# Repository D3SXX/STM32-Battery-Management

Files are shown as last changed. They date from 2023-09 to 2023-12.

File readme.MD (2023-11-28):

# STM32 BATTERY MANAGEMENT PROJECT (DEVELOPMENT BRANCH)

For project information use [docs/project-information.MD](/docs/project-information.MD)

# Project Directory Map

/docs ------ Different documentations.

/docs/KiCAD Files ------ KiCAD schematics, simulations and PCB layouts.

/examples ------ researching study projects about mux, adc using LL library.

/lib ------ Project libraries.

/src ----- main.c

/scrum_reports ------ self explaintory.

/iot-ticket ------ iot-ticket related project

/iot-ticket/iotticket ------ iot-ticket client library.

/iot-ticket/fucking_mockingdata.py ------ the python Modbus Master/Cient to IoT-Ticket client gateway application. Naming is "bit" controversial, but it is what it is.

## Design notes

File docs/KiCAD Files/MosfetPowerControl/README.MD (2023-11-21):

# Mosfet Power Control

## Mosfet Basics

### Types

The **metal-oxide-semiconductor field-effect transistor** ( **MOSFET** ,  **MOS-FET** , or  **MOS FET** ) is a type of [field-effect transistor](https://en.wikipedia.org/wiki/Field-effect_transistor "Field-effect transistor") (FET), is basically a digital switche controlled by it's gate. There are normally three terminals, Drain, Source and Gate. The gate controls the current flow through D-S or S-D. There are N-Channel mosfet, P-Channel mosfet. And there enhancement type and depletion type of each.
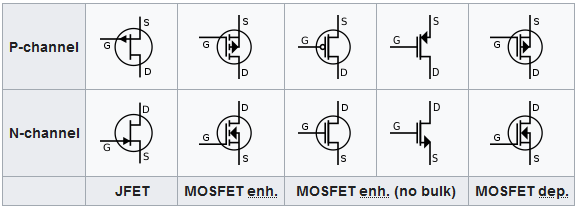
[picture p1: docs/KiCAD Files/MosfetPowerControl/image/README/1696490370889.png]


https://en.wikipedia.org/wiki/MOSFET

### Body diode

The existance of body diode in mosfet causing the current could flow to the forward direction of the body diode, even though the gate is off.

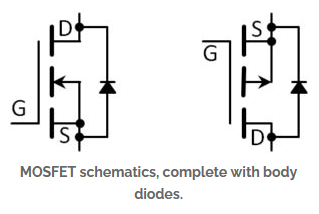
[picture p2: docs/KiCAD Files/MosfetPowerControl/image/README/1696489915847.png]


# FDS6890A

FDS6890A is Dual N-channel mosfets in SO-8 package. With following characteristics.
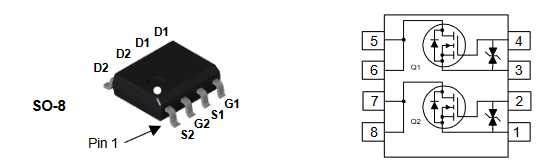
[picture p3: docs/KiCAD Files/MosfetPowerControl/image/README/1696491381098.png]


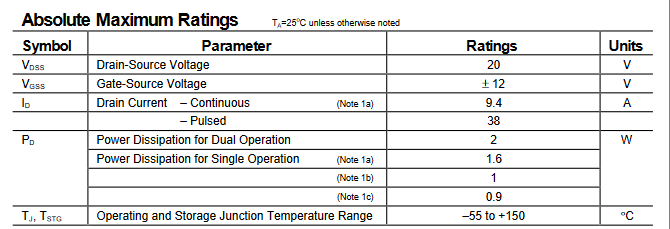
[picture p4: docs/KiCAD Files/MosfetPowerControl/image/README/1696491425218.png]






## Terminology

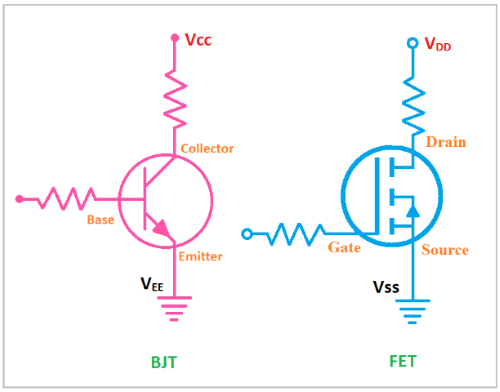
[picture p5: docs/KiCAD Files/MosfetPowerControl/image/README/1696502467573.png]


https://woopcb.com/blog/what-is-vcc-vss-vdd-vee-in-electronics

## N-Channel Mosfets in series

N-Channel Mosfets in series offer extra control of the current due to in body diode. And puting mosfet-series-array in parrallel allow the mosfets to handle more current. In theory I_total_max = I_mosfet_max * N

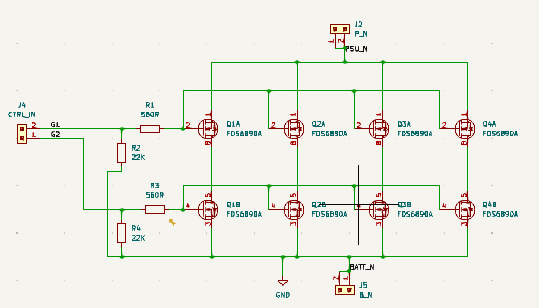
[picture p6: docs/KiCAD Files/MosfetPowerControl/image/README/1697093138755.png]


Be aware, the physical diodes D1 and D2 were added only for demostration of in body diode of the N-Channel mosfet. There's no actual physical dioded added to the circuit.

The current control follows the following truth table.

| Gate 0 | Gate 1 | Current Direction | Charing | Discharging |
| --- | --- | --- | --- | --- |
| 0 | 0 | None | NA | NA |
| 0 | 1 | Up to Bottom | OFF | ON |
| 1 | 0 | Bottom to Up | ON | OFF |
| 1 | 1 | Bidirectio | ON | ON |

https://www.powerelectronictips.com/remember-mosfet-body-diode-faq/

* Pull Down Resister: 22K
* IO current limit Resister: Ceil(3.3V / 25mA * 4) = 560R

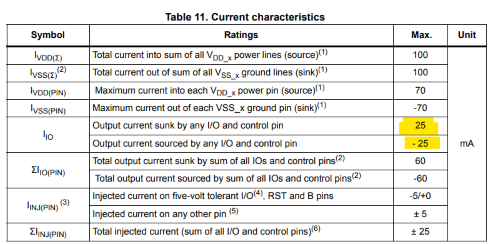
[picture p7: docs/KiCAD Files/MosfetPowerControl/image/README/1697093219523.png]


### PCB Circuit

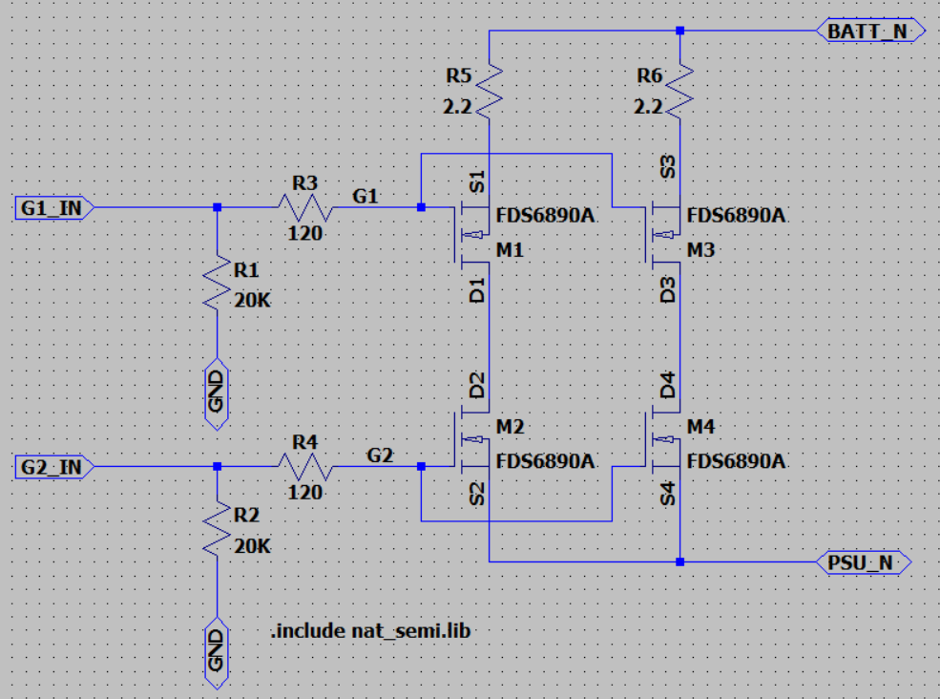
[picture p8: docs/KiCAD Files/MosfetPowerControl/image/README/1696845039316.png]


### Simulation

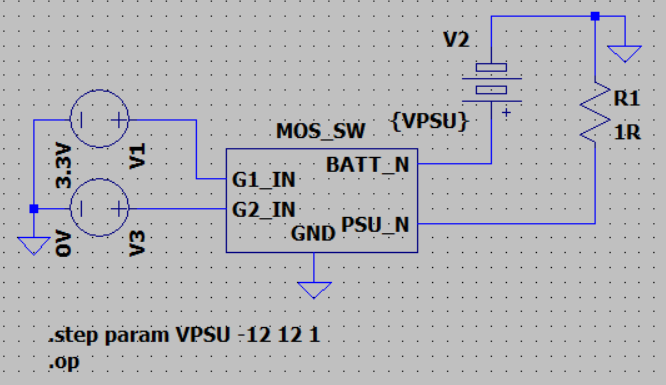
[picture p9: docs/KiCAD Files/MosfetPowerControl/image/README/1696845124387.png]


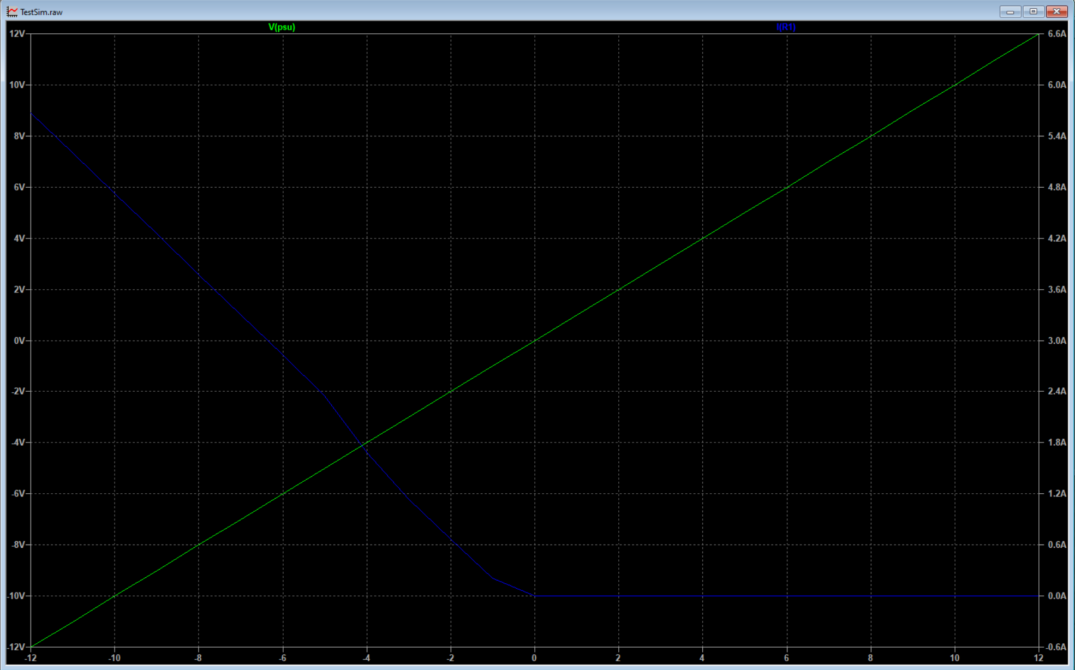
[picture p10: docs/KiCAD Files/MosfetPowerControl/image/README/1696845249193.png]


## Control Logic In Practice

The maximum On state drain-source current and Off state drain-source diode forward current are 9.4A and 1.3A respectively. Therefore, we couldn't simply just allow the charging and discharging to occure without extra control.

- Start condition (0, 0)
- Discharging not allowed, charging allowed. (0, 1)
- Now the charging current ramps up --> also turn on the discharging MOSFET, say 1A. (1, 1)
- Charging drops below 1A, disable discharging MOSFET again to make sure we don't get to discharging. (0, 1)

--> keep in mind that
battery can either be charging or discharging, so if there is enough
power on the input (say solar) to power the load and charge battery,
nothing will come from the battery. If the load is higher than what
solar can provide, part of the required power comes from the battery.

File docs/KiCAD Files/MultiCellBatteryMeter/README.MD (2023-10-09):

# Terminology

## Rail-To-Rail OPAMP

The power supply units of PCs and other devices incorporate multiple DC power supplies. A power supply line provided by a power supply unit is referred to as a power rail. The entire range from the maximum voltage of a power line (V ~CC~ ) to its minimum voltage (GND or minimum negative voltage, V ~EE~ ) is referred to as rail-to-rail.
"*Rail-to-rail* " is a marketing term used to describe an op amp whose dynamic range is able to reach the extremes of the supply voltage. This can refer to either the output or both the input and output.

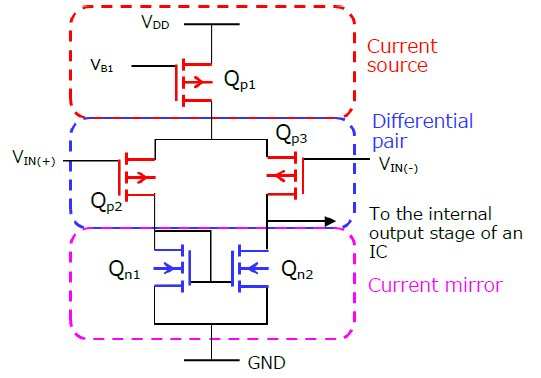
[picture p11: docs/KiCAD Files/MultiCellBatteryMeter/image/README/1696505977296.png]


https://toshiba.semicon-storage.com/ap-en/semiconductor/knowledge/faq/linear_opamp/what-does-rail-to-rail-mean.html

https://electronics.stackexchange.com/questions/224159/what-does-rail-to-rail-output-opamp-mean

## Electric Shunt

A **shunt** is a device that is designed to provide a low-resistance path for an electrical current in a circuit. There are many applications of an electric shunt, such as Defective device bypass, Photovoltaics, Lightning arrester and Current measuring.

### Current Measuring Shunt

Basically it is the technique to which uses a very small known resistor in series to the circuit to calculate the current by measuring the voltage difference between the resistor. There different positons such as High Side and Low Side. There can be circuit for Uni-direction current sensing and Bi-direction current sensing. In this project Bi-direction current sensing design was used, because of the current flow of the battery are bi-directional, charing and discharging.

https://www.analog.com/en/app-notes/an-105fa.html

In thie project, the shunt needs to detect bi-directional current. Therefore, the extra circuit is needed to convert voltage from range[-4V, +4-V] to range[0V, 3V].

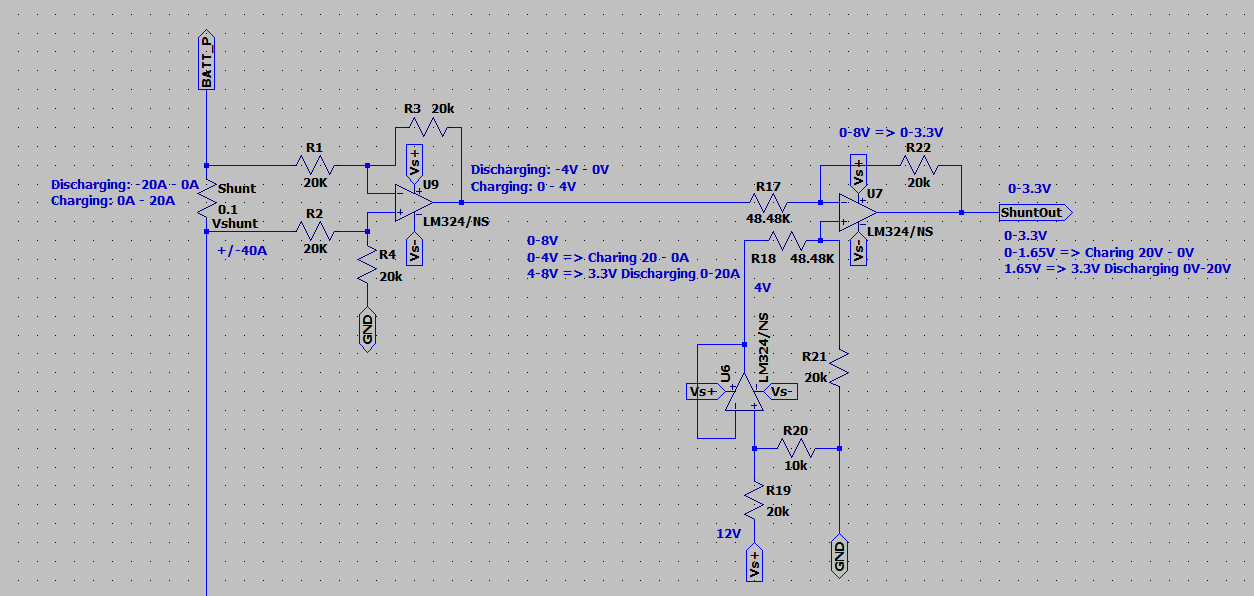
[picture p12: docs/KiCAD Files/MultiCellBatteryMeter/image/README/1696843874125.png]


### Differential Input Amplifier

As the name implies.

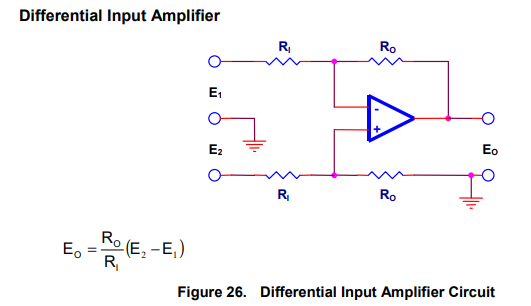
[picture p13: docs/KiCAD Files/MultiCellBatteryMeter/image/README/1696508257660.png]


Texas Instrument 00_opam_handbook.pdf P.24

## Multi Cell Battery Meter Circuit

In order to measure each cell's voltage accurately, Differential Input Amplifiers were used. And a 3-to-8 multiplexer was used to reduce the ADC I/O demands on Microcontroller. This design also left room for four extra battery cells. 

### Indivitual Voltage Meter Circuit

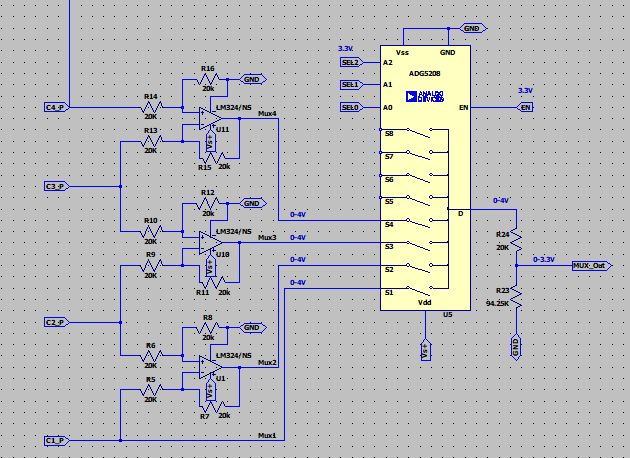
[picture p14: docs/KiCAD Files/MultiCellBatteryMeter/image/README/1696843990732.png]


### Simulation Circuit

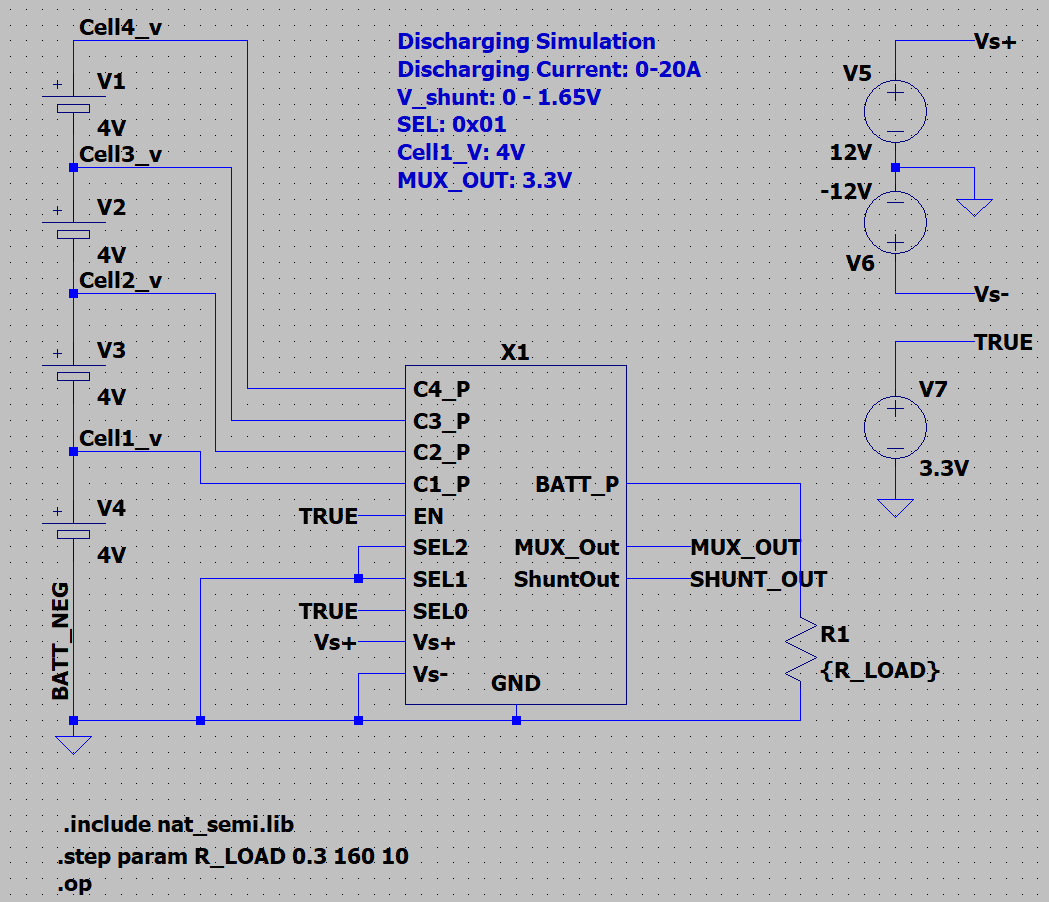
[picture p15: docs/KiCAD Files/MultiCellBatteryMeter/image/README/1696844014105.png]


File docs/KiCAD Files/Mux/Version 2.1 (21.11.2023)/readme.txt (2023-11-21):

Mux board version 2.1 by Vlad R.
Modified version of Mux board
Changes are -
Add physical labels to the outputs
Better copper pour

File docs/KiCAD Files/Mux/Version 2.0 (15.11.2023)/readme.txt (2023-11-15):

Mux board version 2.0 by Vlad R.
Modified version of Mux board
Changes are -
Names for pins and connections were taken straight from the datasheet for consistency
The Schematic was simplified by using more different output socket pins
Pcb was remade from scratch to reduce the number of jumpwires (now it is 0) and to make it more easier to set up.
Also pcb design now uses only 0.8mm traces

Changes from the already made PCB -
Name is now mirrored correctly

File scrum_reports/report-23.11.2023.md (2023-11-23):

# Report 23.11.2023

- Host - Vladislav

- Participants - Siyuan, Samuel, Sergiu

## Group Progress:

- ### Siyuan:
Added Pin Mappings and modbus function documentation (excel)

### Software Libraries
-	libadc
-	libmux
-	libbattery-manager

### Unit-Testings
#### Native Testing
-	test_adc
-	test_battery-manager
-	test_crc

### Hardware in Loop (embedded) Testing
-	test_adc
-	test_modbus
-	test_mosfet
-	test_mux

### PCB
-	soldered and tested mosfet control module

### Bugfixes
#### Bugs found during testing
-	adc
-	mux
-	modbus
-	battery-manager

- ### Samuel:
Made PCB for OP AMP circuit, tested the opAmp pcb, helped to make adc, helped with module control testing

- ### Sergiu: 
Light PCb design design, Made some PCBs, changed/fixed Unit tests

- ### Vladislav: 
Mux board, Unit tests

## Block:

- Siyuan: Where is the time?

- Samuel: Nothing to do

- Sergiu: A little bit of everything

- Vladislav: Not enough for everything

## TODO:

- Siyuan - FFinish the software, System Testing

- Samuel: Look at unit testing, System Testing

- Sergiu: Test some PCBs, System Testing

- Vladislav: Update code for mux testing, System Testing

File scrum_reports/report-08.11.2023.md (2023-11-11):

# Report 08.11.2023

- Host - Siyuan
- Participants - Vladislav, Samuel, Sergiu

## Group Progress:

- Siyuan: LM324 QUAD modelling in NGSpice,
MultiCellVoltMeter Schema simulation + PCB on kicad,
ShuntCurrentSensor Schema simulation + PCB on kicad,
Mux module         Schema simulation + PCB on kicad,
PlatformIO Unit Test setup for Native (test without the hardware)

- Samuel: Protyping the shunt current sensor on copperboard

- Vladislav: Sweden!!!

- Sergiu: Tried PCB design, Sweden

## Block:

- Siyuan: Where is the time?

- Samuel: Waiting for PCB design, waiting for Mosfet PCB arrive

- Vladislav: Learning new stuff

- Sergiu: Time management

## TODO:
- Siyuan - PCBs, embedded Testing,
Organize the project directory according to PlatformIO for easier Testing.

- Samuel: Make PCBs

- Vladislav: CI for github, help with making PCB

- Sergiu: Unit Test, soldering the PCB, joule Heating formula

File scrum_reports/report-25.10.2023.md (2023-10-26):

# Report 25.10.2023

- Host - Siyuan

- Participants - Samuel, Vladislav 

## Group progress:

- Samuel: Had own hobby studies on oscillators

- Vladislav: Vacation

- Siyuan: Researching ADC and designing the software architecture

## Block:

- Samuel: Nothing to do

- Vladislav: Nothing to do

- Siyuan: Limited time, STM32 is missing (And Found).

## TODO:

- Samuel: Will do the current sensing circuit and PCB

- Vladislav: LM35 Temperature

- Siyuan: Optimize, refactor and ADC code from Vlad.
Test the code.
Organize the Git repo.
Theory Support if needed.

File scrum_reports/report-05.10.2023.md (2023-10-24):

# Report 05.10.2023

- Host : Siyuan
- Participants: Samuel, Vladislav, Sergiu

## Group Progress:

- Siyuan: Modbus is ready, MOSFET control circuit , documentation for Mosfets
- Sergiu: Made ADC circuit circuit
- Sam: MOSFET circuit, electrical design of it, tested it using spice , breadboard
Vlad: ADC Measurements 

## TODO:
- Sam: Make a proper PCB
- Sergiu: Make a proper PCB, merge all branches 
- Siyuan: Logic, rtos

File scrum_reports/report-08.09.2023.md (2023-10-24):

# Report 08.09.2023 

- Host – Vladislav 

- Participants – Siyuan, Samuel, Sergiu 

## Github

- Is anyone experiencing any problems with github? 

- Everyone has access and can edit? 

### All - Good 

### Project 

- Everyone understands concept? 

- A quick run thru the project details so everyone understands 

- A quick description of the project will be published on GitHub with all the details 

### All - good 

## Embedded side

- What are we measuring? 

- How do we measure it? 

- What parts needed to be done 

- Software for project 

- CI/CD and unit testing (was only mentioned) 

### All – good, information can be found in docs/project-info.md 

## Assigned tasks

### Vladislav:

- MOSFET driven switch (both charging and discharging)
Temperature monitoring

### Samuel:

- Individual battery cell voltages

### Sergiu:

- STM32 controller with over/under voltage per cell, over/under temperature (charge: 0C to 40C and discharge: -20C to 40C)

### Siyuan:

- Communication of cell voltages over Modbus RTU
Some kind of visualization of the Modbus data

## Notes

- Some of the assigned tasks will be made in pairs with someone.

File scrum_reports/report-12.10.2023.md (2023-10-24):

# Report 12.10.2023 

- Host - Vladislav  

- Participants - Siyuan, Sergiu 

## Group Progress: 

- Siyuan: Invistigated FreeRTOS, Invistigated ADC Hardware features: Single/Contineous Mode, ScanMode, AnalogWatchDog, Two ADCs with 12 channels. Simulation and PCB for Mosfet Power Switch Module, Simulation circuit of Individual Cell Voltage meter, Simulation circuit of Battery Current meter 

- Sergiu: Copper Board and PCB board for ADC design, researched code for temperature measurement 

- Vladislav: Mux for Kicad, added logs for previous scrums 

## Block:  

- Siyuan: Some PCB design principles, according to the calculator I need 18.7156mm trace width, whaaat?, Lack of Electronics knowledge, Lack of PCB design knowledge 

## TODO: 

- Siyuan: Some customer requirement meeting again with Johan. 

- Sergiu: Design PCB Board for ADC 

- Vladislav: Copper board for ADC, mux

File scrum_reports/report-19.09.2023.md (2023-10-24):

# Report 19.09.2023 

- Host - Vladislav 

- Participants - Siyuan, Samuel, Sergiu

## Group Progress: 

- Siyuan: Studied LL, Clock 

- Samuel: researched his issue on github (temperature cell) 

- Sergiu: Studied LL and wrote code for lm35 using LL, Grafana implementation 

- Vladislav: Studied LL and helped writing code for lm35 using LL, Multiplexer, MOSFET research 

## TODO: 

- Siyuan: Implement correct clock configuration 

- Samuel: Use AIV 

- Sergiu: What we host the project on, make a database for, put some issues in backlog and organize them better on github. 

- Vladislav: MOSFET, Multiplexer for reading temperature 

- Everyone: Start making steps for making a PCB 

## Problems facing: 

- Siyuan: LL and STM32 Clock – either implement re-flow of internal clock and work with external clock 

- Vladislav: MOSFET design 

## Question: 

- Siyuan: What grafana run on (C/python, etc.) -> Sergiu response – the language doesn’t matter 

- How do you send data from microcontroller to grafana 

- There is a script that will do everything for receiving and feeding grafana (using serial)

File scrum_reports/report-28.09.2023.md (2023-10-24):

# Report 28.09.2023

- Host - Vladislav 

- Participants - Siyuan, Samuel, Sergiu

## Group progress: 

- Vladislav - MUX Branch, power efficiency of code 

- Siyuan : Complied MODBUS Code, Plan B for Data visualisation 

- Sergiu & Samuel : Circuit design 

## TODO: 

- Check the power circuit on a breadboard 

- Finalize the PCB Design 

- Check the zener diode for reading negative voltages 

## Question: 

- Sergiu: Voltage Design 

- Siyuan : Have you changes any pcb design -> Sergiu – No, we need to check everything on breadboard

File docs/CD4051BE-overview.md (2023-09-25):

# Texas Instruments CD4051BE single 8-Channel multiplexer

### Quick recap

- The CD4051B is a single 8-Channel multiplexer having three
binary control inputs, A, B, and C, and an inhibit input. The
three binary signals select 1 of 8 channels to be turned on,
and connect one of the 8 inputs to the output. ([CD4051BE Datasheet p. 2](/datasheet/CD4051BE-Texas-Instruments.pdf))

- Basically  this means that the chip operates based on its own truth table, and works as a passthrough decoder. It receives A (Pin 11), B (Pin 10), C (Pin 9) and INHIBIT (Pin 6), which is always 0 and from it checks its own truth table and passes one of its inputs (IN/OUT Channels) to the COM OUT/IN (Pin 3). This pass can be made from both sides, allowing, for example, the passage of 5 Volts from COM OUT/IN to channel 0.

### Connections

- The chip required at least 3 Volts and has maximum operational VDD of 20 Volts (Pin 16)
- The chip requires only 1 nessesary ground connection VSS (Pin 9), and 1 unnessesary for INH (Pin 6). The reason to connect INH to the ground is because it is always 0 (from the [CD4051BE Datasheet p. 2](/datasheet/CD4051BE-Texas-Instruments.pdf) "When
a logic “1” is present at the inhibit input terminal, all
channels are off.") and this frees up an additional pin on the microcontroller board.
- A (Pin 11), B (Pin 10), C (Pin 9) must be connected to digital pins on the board.
- Channels (Chronologically pins 13,14,15,12,1,5,2,4) are measured from 0 to 7 and can either be connected or left unconnected to anything, (e.g. connected to the temperature sensore output).

### Truth Table ([CD4051BE Datasheet p. 5](/datasheet/CD4051BE-Texas-Instruments.pdf))

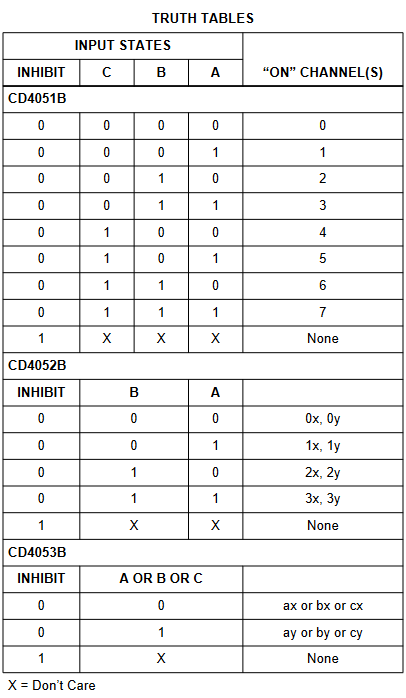
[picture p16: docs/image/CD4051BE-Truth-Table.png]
CD4051BE-Truth-Table


### Pinout [CD4051BE Datasheet p. 3](/datasheet/CD4051BE-Texas-Instruments.pdf)

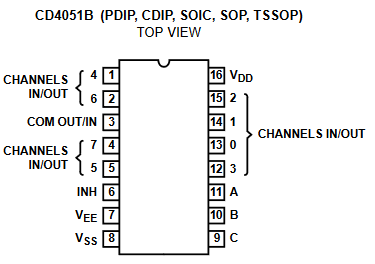
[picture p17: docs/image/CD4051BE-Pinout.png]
CD4051BE-Pinout


## Chip

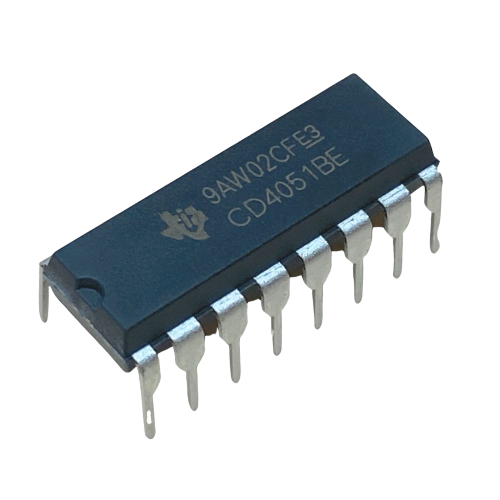
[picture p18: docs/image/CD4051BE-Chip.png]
CD4051BE-Chip


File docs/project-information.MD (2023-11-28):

# Description

The Batter Management System is for the VAMK 4th year course [IITS2207-3005 Embedded Systems Programming and Project](https://portal.vamk.fi/course/view.php?id=16051). The objective is for students get familiar with the modern CI/CD embedded system development. The team consists four students, and each student would take roles of project manager/scrum master, software designer, hardware designer.

STM32L152RE microcontroller board was used to monitor the status of four LiFePo4 cells in seriers such as voltage, current and temperature. Depends on the monitored status the uC would set battery current flow into charging-only, discharging-only or bidirectional. The modbus slave/server was implemented for hosting all the status value. A python modbus master/client was developed as a gateway for fetch status data from BMS and pushing it to the cloud for visualization. The cloud service used was Wapice IoT-Ticket 3.

# Requirement Specification

- MOSFET driven switch (both charging and discharging)
- Temperature monitoring
- Individual battery cell voltages
- STM32 controller with over/under voltage per cell, over/under temperature (charge: 0C to 40C and discharge: -20C to 40C)
- Communication of cell voltages over Modbus RTU
- Some kind of visualization of the Modbus data

# Hardware

- STM32 Nucleo L152RE.
- MAX3485 RS485 to USART converter.
- USB-RS485-WE-1800-BT USB to RS485 converter.
- FDS6898A MOSFETS.
- CD4051BE Multiplexer.
- LM324 OP AMPS.
- LM35 Ananlog Thermalmeter.
- Resisters.
- Breadboards.

# Environment

- Language - C
- Software
  - PlatformIO (STM32CUBE framework) for researching.
  - PlatformIO (CMSIS framework) for development.
  - Unity framwork for unit testing.
  - Python 3.11.6.
  - Minimum Modbus Library.
  - IoT-Ticket 3 Library.
  - Github for CI/CD.

# Coding Conventions

- See [cpp-naming-convention.MD](./cpp-naming-convention.MD)
- See [branch-naming.convention.MD](./branch-naming-convention.MD)

# Scrum

- See /scrum_reports

# Documentation index

- [Temperature Sensor Analysis](./temperature-sensors.MD)
- [Git Action for CI](./git-action-for-ci.MD)
- [Atolic TrueStudio Pipeline](./atollic-true-studio-pipeline.MD)
- [CD4051BE Multiplexer Overview](./CD4051BE-overview.md)
- [Multicell Battery Meter Module](./KiCAD%20Files/MultiCellBatteryMeter/README.MD)
- [Mosfet Power Control Module](./KiCAD%20Files/MosfetPowerControl/README.MD)

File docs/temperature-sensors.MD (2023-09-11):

# Temperature Monitoring

# Thermocouple

### Quick Description

- A thermocouple is a sensor composed of two different types of metal joined together. While there are several types of thermocouples available, only K are practical for this project, so it will be covered.

### Thermocouple Type K

- Temperature Range: The temperature range of thermocouple type K varies depending on the specific model, but the average range typically spans from -40°C to +250°C.

### Usage with STM32

- To measure the temperature using an STM32 microcontroller, you will need a converter such as the MAX6675 chip. The MAX6675 is a K-Thermocouple-to-Digital Converter capable of handling cold-junction compensation and digitizing the signal from the K-Thermocouple. It provides a 12-bit resolution output signal (0.25 degrees resolution). The only disadvantage of that conversion is that it will not cover negative temperature, since the scope of a chip is from 0 to +1024 Degrees Celsius. See Reference for more information.

### Advantages

- Provides a wide range of temperature measurement.

# NTC Thermistor

### Quick Description

- A Negative Temperature Coefficient (NTC) thermistor is a sensor made of semiconductor material. Various variants of NTC thermistors are available, including those with a ring connector and fixed wire. NTC thermistors exhibit a non-linear resistance-temperature characteristic, which means their resistance changes rapidly over a relatively small temperature range. The typical temperature range for NTC thermistors is from -40°C to +100°C.

### Usage with STM32

- To measure an NTC thermistor, a simple voltage divider circuit can be constructed with a pull-down resistor. This allows the measurement of the thermistor's resistance, which can then be used to calculate the temperature using a formula that relates resistance to degrees Celsius.

### Advantages

- Cost-effective.
- Ease of Operation.

# RTD Sensor

### Quick description

- An Resistance Temperature Detector sensor is constructed from nearly pure platinum. RTDs can be available in various forms, including pure ceramic sensors, straight wire with a steel ending, and versions with ring connectors. For this project, we will focus on the PT100 and PT1000 RTDs, as they are the most common and readily available options.

### PT100 and PT1000

- PT100 and PT1000 sensors have different resistances and are not interchangeable. Both sensors exhibit a resistance of 100 ohms and 1000 ohms, respectively, at 0 degrees Celsius. This difference means that the PT1000 provides better accuracy due to its wider range of resistance values. However, it may be more challenging to find PT1000 sensors with wire connections.

### Usage with STM32

- To measure an RTD sensor, a voltage divider circuit (similar to NTC thermistor measurement) can be used to measure the voltage. This voltage can then be converted into resistance using the voltage divider formula and further converted into temperature using the resistance-to-temperature formula.

### Advantages

- Provides highly accurate and stable temperature measurements.
- Requires minimal calibration.

# IC Sensor

### Quick description

- Integrated Circuit Temperature Sensors are semiconductor devices primarily made of silicon. They provide the most linear output comparing to the rest sensors. The operation temperature is usually from -40 to +100 Celsius degrees.

### Usage with STM32

- To measure IC sensor it is as simple as just connecting it to the analog input of STM32 board, reading the values and applying formula to convert it to Celsius.

### Advantages

- Ease of Operation.
- Low Cost.
- Linearity.

# Which one to select?

1. **IC sensor** - The most preferred one because of ease of operation and linearity (~2 eur), but it might be not that accurate in operation (0.5°C Ensured Accuracy) and hard to mount.

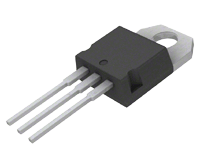
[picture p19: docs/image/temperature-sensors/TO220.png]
TO220
<p style="text-align:center;"></p><p style="text-align:center;">LM35DT (TO220)</p>

2. **NTC Thermistor** - Pretty accurate (±3%), not that expensive (~4 eur), and supports ring mount.

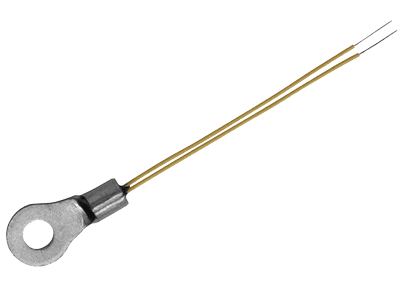
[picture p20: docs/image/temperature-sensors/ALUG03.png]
ALUG03
<p style="text-align:center;"></p><p style="text-align:center;">ALUG03-10K</p>

3. **PT100/PT1000** - Very accurate (±0.3°C), a little bit expensive (~6 eur), might be harder to control, and supports a ring mount as well.

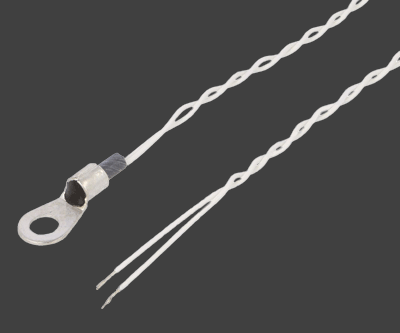
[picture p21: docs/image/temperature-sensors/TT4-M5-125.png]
TT4-M5-125
<p style="text-align:center;"></p><p style="text-align:center;">TT4M-PT100B-T125-M5-50</p>

4. **Thermocouple** - Accurate (±0.4%), rarely expensive (~5-20 eur), has a big range of temperatures to measure, is hard to measure, and would be an overkill.

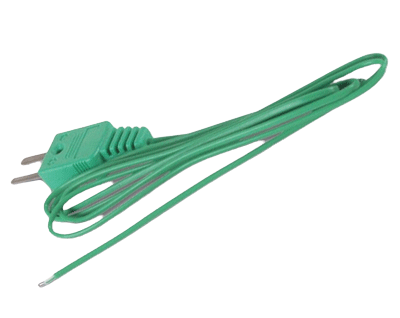
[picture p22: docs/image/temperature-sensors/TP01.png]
TP01
<p style="text-align:center;"></p><p style="text-align:center;">TP01</p>

# References

### Thermocouple
- [Thermocouple probes](https://www.omega.com/en-us/resources/thermocouple-hub#:~:text=What%20is%20a%20thermocouple%3F,correlated%20back%20to%20the%20temperature.)
- [Working with STM32 and Sensors: Thermocouple TypeK](https://blog.embeddedexpert.io/?p=806)
- [MAX6675 Cold-Junction-Compensated K-Thermocouple](https://www.analog.com/media/en/technical-documentation/data-sheets/MAX6675.pdf)

### NTC Thermistor

- [What Is An NTC Thermistor](https://www.ametherm.com/thermistor/what-is-an-ntc-thermistor)
- [[For Arduino and STM32] Library for working with a NTC thermistor.](https://github.com/YuriiSalimov/NTC_Thermistor)

### RTD Sensor

- [Resistance thermometer](https://en.wikipedia.org/wiki/Resistance_thermometer)

### IC Sensor

- [IC Sensors](https://www.omega.com/en-us/resources/integrated-circuit-sensors)
- [STM32 Nucleo and LM35 temperature sensor](http://www.armlearning.com/code/mbed/stm32-nucleo-lm35-temperature-sensor.php)

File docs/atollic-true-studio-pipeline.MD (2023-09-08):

# Introduction

Atollic TrueSTUDIO is a C/C++ IDE for STM32 microcontroller and breakout boards. It is built on Eclipse ^®^ , CDT ^™^ , GCC and GDB, while it is easy to use the GUI for development, command line tools are available for CI/CD pipeline. As the time of writing this documentation, the version used was TrueSTUDIO 9.3.0.

HEADLESS BUILD

This is intended for Managed Mode projects that are to be integrated into script-
controlled builds, such as nightly builds on build servers for continuous integration process
methods, etc. It is possible to start a build process from the operating system command
line also for Managed Mode projects. The IDE GUI is never displayed in this case, and the
user does not have to interact manually with the IDE at all.
The IDE installation folder, e.g. C:\Program Files (x86)\Atollic\TrueSTUDIO for
STM32 9.0.0\ide, contains the file headless.bat, which is used for running
headless builds. 

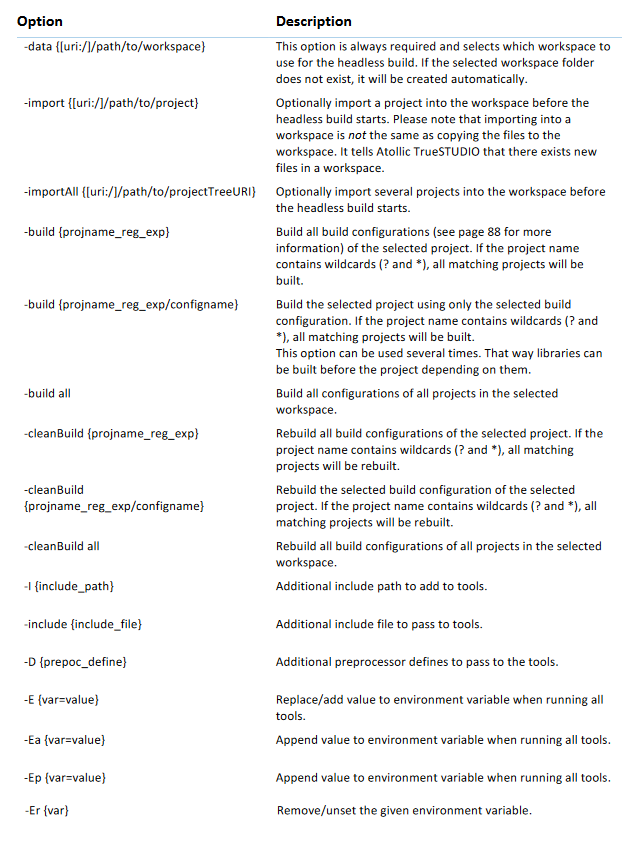
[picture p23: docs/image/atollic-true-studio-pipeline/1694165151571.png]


atollic-truestudio-9.3.0 manual p. 110 - 116

# References

[TrueSTUDIO Installation Guide](https://www.st.com/resource/en/user_manual/truestudio_installation_guide-truestudio-installation-guide-stmicroelectronics.pdf)

[TrueSTUDIO Upgrade Guide](https://www.st.com/resource/en/user_manual/truestudio_upgradeguide-truestudio-upgrade-guide-stmicroelectronics.pdf)

[TrueSTUDIO UserManual 9.3.0](https://www.st.com/resource/en/user_manual/usermanual_truestudio-user-manual-for-truestudio-930-stmicroelectronics.pdf)

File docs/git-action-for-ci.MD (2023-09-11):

# **Git Action for Continuous Integration**

### Quick recap
Continuous integration (CI for short) is a practice used to reduce the amount of errors, shorten the time for developing a code and make the merging process easier. It involves frequent commits during the development cycle. After each commit, the server (Github Actions in our case) will build and test the code for errors. 

### Continuous integration using GitHub Actions
The GitHub Action’s workflow can work by using [Github](https://docs.github.com/en/actions/using-github-hosted-runners/about-github-hosted-runners) or [Self-hosted ](https://docs.github.com/en/actions/hosting-your-own-runners/managing-self-hosted-runners/about-self-hosted-runners) virtual machines. The workflow should be configured to run when an event occurs like committing to a repository. GitHub will validate the code by using CI tests and indicate if there is an error. When successful, the code will be able to be reviewed by other team members.

### GitHub-hosted runner usage
To use, first, the job should be created with `runs-on`. A full list of available runner images can be [found here](https://docs.github.com/en/actions/using-github-hosted-runners/about-github-hosted-runners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). GitHub will provision a new virtual machine for each job. 

### Workflow creation
Workflow is made by using a YAML file, in which each job script (actions and dependencies) is specified. When the job is done, the output of it can be seen in GitHub UI.

An example of a YAML file that is using Ubuntu

```
name: CI for STM32 Project

on:
  push:
    branches:
      - main

jobs:
  build:
    runs-on: ubuntu-latest
    steps:
      - name: Checkout code
        uses: actions/checkout@v2

      - name: Set up ARM GCC toolchain
        uses: sstaub/setup-arm-embedded@v2
        with:
          version: '10'

      - name: Build STM32 project
        run: |
          cd path/to/your/stm32/project
          pio run -e nucleo_l152re -t upload
        env:
          PATH: ${{ env.ARM_EABI_PATH }}:$PATH

      - name: Run tests
        run: |
          cd path/to/your/tests
          ./run_tests.sh
```

**The most interesting syntax in this example**

- `name` sets a name for the GitHub Actions workflow
- `on` specifies when the workflow should be triggered. 
- `jobs` define the jobs that will run in the workflow.
- `build` defines a job
- `runs-on` specifies the type of virtual machine (runner) the job will run on.
- `steps` Within a job defines a series of steps that execute specific tasks.
- `name` sets a name for the step.
- `uses` specifies an action to use.
- `env` allows you to set environment variables for steps.

# References

- For terminology explanation use https://docs.github.com/en/actions/learn-github-actions/understanding-github-actions
- For CI in-depth explanation use https://docs.github.com/en/actions/automating-builds-and-tests/about-continuous-integration
- For YAML in-depth explanation use https://docs.github.com/en/actions/using-workflows/workflow-syntax-for-github-actions

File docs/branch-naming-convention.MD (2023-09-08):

# Main branches

master/main -> releases only

development -> feature, bugfix, test, doc merge to here first

# Supporting branches

feature/some-feature

bugfix/some-bugfix

test/some-test

doc/some-document-name

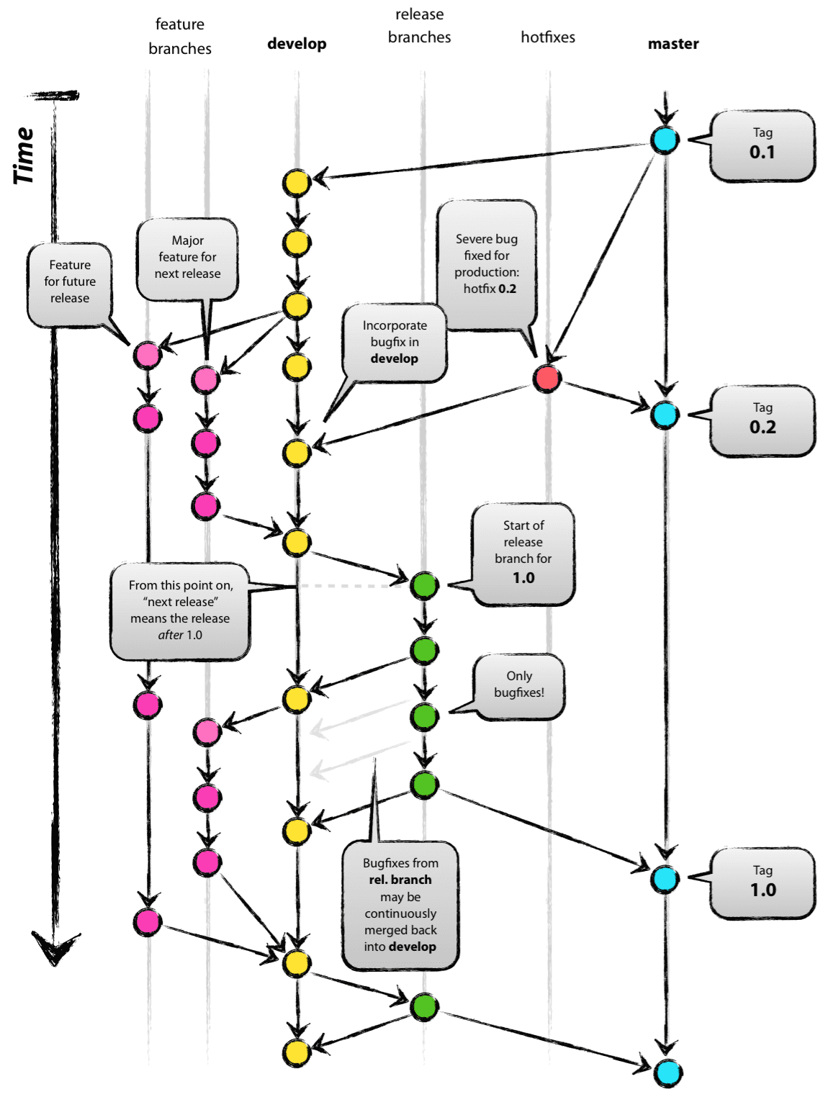
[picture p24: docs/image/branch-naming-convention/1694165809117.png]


# Reference

[Vincent Driessen&#39;s Git branching model](https://nvie.com/posts/a-successful-git-branching-model/)

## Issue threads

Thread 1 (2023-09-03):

Research Build and Testing workflow for PIO in CLI

SergiuPetrut, 2023-09-03:
# Researching and documenting how PlatformIO (PIO) manages builds and unit testing in a CLI environment

## Making a project

Simple as `pio project init --board nucleo_l152re`

## Building the project

`pio run`. Process (build) all environments specified in [“platformio.ini” (Project Configuration File)](https://docs.platformio.org/en/stable/projectconf/index.html#projectconf)

 `pio run --target upload` - Build project and upload firmware to the all devices specified in [“platformio.ini” (Project Configuration File)](https://docs.platformio.org/en/stable/projectconf/index.html#projectconf)

`pio run --target clean` -  Clean project (delete compiled objects)

`pio run -e nucleo_l152re` -  Process only nucleo_l152re environment

`pio run -e nucleo_l152re -t upload` -  Build project only for nucleo_l152re and upload firmware.

## Unit Testing

The recommended framework for running unit tests within PIO is the Unity framework.
Doctest and Googletest are also supported.

Using any testing framework requires making a test file (or files, depending on what component of the project you want to test)  within the `test` directory in the project files.

The Unity framework requires a couple of functions :

`setUp()` : lets you run anything _before_ a test
`tearDown` : lets you run anything _after_ a test

They both accept no args and return nothing.

Inside the main() loop, the first thing that needs to be done is to call `UNITY_BEGIN();`. Afterwards, each test function may be  ran with `RUN_TEST( [insert name of test func here] )`. The loop needs to be ended with `UNITY_END()`. `UNITY_END()` is what actually triggers each function to run, so having an individual `RUN_TEST` for each and every function is crucial.

Here is a code snippet showing what a test file may look like :
```
#include "unity.h"
#include "file_to_test.h"

void setUp(void) {
  // set stuff up here
}

void tearDown(void) {
  // clean stuff up here
}

void test_function_should_doBlahAndBlah(void) {
  // test stuff
}

void test_function_should_doAlsoDoBlah(void) {
  // more test stuff
}

int runUnityTests(void) {
  UNITY_BEGIN();
  RUN_TEST(test_function_should_doBlahAndBlah);
  RUN_TEST(test_function_should_doAlsoDoBlah);
  return UNITY_END();
}
```

More information is available here on Unit Testing and many more things regarding PIO : https://docs.platformio.org/en/stable/advanced/unit-testing/index.html#unit-testing

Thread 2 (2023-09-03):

Check the GIT action for CI

SergiuPetrut, 2023-09-03:
### **Git Action for Continuous Integration**

### Quick recap
Continuous integration (CI for short) is a practice used to reduce the amount of errors, shorten the time for developing a code and make the merging process easier. It involves frequent commits during the development cycle. After each commit, the server (Github Actions in our case) will build and test the code for errors.

### Continuous integration using GitHub Actions
The GitHub Action’s workflow can work by using [Github](https://docs.github.com/en/actions/using-github-hosted-runners/about-github-hosted-runners) or [Self-hosted ](https://docs.github.com/en/actions/hosting-your-own-runners/managing-self-hosted-runners/about-self-hosted-runners) virtual machines. The workflow should be configured to run when an event occurs like committing to a repository. GitHub will validate the code by using CI tests and indicate if there is an error. When successful, the code will be able to be reviewed by other team members.

### GitHub-hosted runner usage
To use, first, the job should be created with `runs-on`. A full list of available runner images can be [found here](https://docs.github.com/en/actions/using-github-hosted-runners/about-github-hosted-runners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). GitHub will provision a new virtual machine for each job.

### Workflow creation
Workflow is made by using a YAML file, in which each job script (actions and dependencies) is specified. When the job is done, the output of it can be seen in GitHub UI.

An example of a YAML file that is using Ubuntu

```
name: CI for STM32 Project

on:
  push:
    branches:
      - main

jobs:
  build:
    runs-on: ubuntu-latest
    steps:
      - name: Checkout code
        uses: actions/checkout@v2

      - name: Set up ARM GCC toolchain
        uses: sstaub/setup-arm-embedded@v2
        with:
          version: '10'

      - name: Build STM32 project
        run: |
          cd path/to/your/stm32/project
          pio run -e nucleo_l152re -t upload
        env:
          PATH: ${{ env.ARM_EABI_PATH }}:$PATH

      - name: Run tests
        run: |
          cd path/to/your/tests
          ./run_tests.sh
```

**The most interesting syntax in this example**

- `name` sets a name for the GitHub Actions workflow
- `on` specifies when the workflow should be triggered.
- `jobs` define the jobs that will run in the workflow.
- `build` defines a job
- `runs-on` specifies the type of virtual machine (runner) the job will run on.
- `steps` Within a job defines a series of steps that execute specific tasks.
- `name` sets a name for the step.
- `uses` specifies an action to use.
- `env` allows you to set environment variables for steps.

For terminology explanation use https://docs.github.com/en/actions/learn-github-actions/understanding-github-actions
For CI in-depth explanation use https://docs.github.com/en/actions/automating-builds-and-tests/about-continuous-integration
For YAML in-depth explanation use https://docs.github.com/en/actions/using-workflows/workflow-syntax-for-github-actions

D3SXX, 2023-09-13:
Added documentation in https://github.com/D3SXX/STM32-Battery-Management/commit/04ee1bc336c00abff4b07b61aa66eb6909133f75

Closed 2023-09-13.

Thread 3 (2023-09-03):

Check STMCube for the Toolchain

SergiuPetrut, 2023-09-03:

Zhguye, 2023-09-19:
External oscillators are more accurate because of the imprecision, temperature/supply voltage dependence, and jitter of the internal oscillators. Currently the settings are configured to use the HSI on 16Mhz (these are the unaltered values for the NUCLEO-L152RE)
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

Maybe useful code if hsi has problems

//

RCC->CFGR |= RCC_CFGR_SW_HSI;				//set hsi as systemclk
while((RCC->CR & RCC_CFGR_SWS_HSI)!= RCC_CFGR_SWS_HSI);

RCC->CFGR |= (RCC_CFGR_MCOSEL_SYSCLK);		//set mco output to sysclk

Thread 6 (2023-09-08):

Add logs and Project info

D3SXX, 2023-09-08:

D3SXX, 2023-09-08:
Added logs and project information in https://github.com/D3SXX/STM32-Battery-Management/commit/83034a64cb9c8d6e325c85b8b8716224257aaea7

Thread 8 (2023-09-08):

Individual battery cell voltages

D3SXX, 2023-09-08:

Zhguye, 2023-09-28:
Tried using op amps to get the voltage values, I think this is the correct approach.
It is possible to use a op-amp as a differential amplifier circuit, which would allow the voltage of a battery cell to be calculated? I don't think this would be a smart option because diff amps give questionable measurements.
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

I think this op-amp circuit I made might work:
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

It might need a second op-amp if the measurements are too inconsistent...?

TruthSeekerX, 2023-10-04:
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

TruthSeekerX, 2023-10-04:
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

TruthSeekerX, 2023-10-04:
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

TruthSeekerX, 2023-10-04:
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

TruthSeekerX, 2023-10-04:
1. We can set up the differential AMP circuit so that, they already convert the expected battery voltage 0-4V to 0-3.3V.
2. There is added shunt for measure the current, and the same logic can be applied for convert 0-40A (0-4V on shunt) to 0-3.3V.
3. Startelec sells 0.1ohm 10W resister for shunt
https://www.starelec.fi/product_info.php?products_id=26101

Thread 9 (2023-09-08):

Temperature monitoring

D3SXX, 2023-09-08:

D3SXX, 2023-09-18:
Progress can be seen here https://github.com/D3SXX/STM32-Battery-Management/tree/feature/temperature-measurement/examples

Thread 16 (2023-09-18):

Test LL Macros

SergiuPetrut, 2023-09-18:

SergiuPetrut, 2023-09-18:
# What is LL?
- LL, standing for Lower Level, is a set of macros that allows manipulating registers

# Why use LL?
- Makes bare-metal code more human readable, while not abstractising the register, like HAL would

# How does it impact performance?
- LL provides no overhead whatsoever, at least not from the code I've written / seen

# Comparing LL to Bare-Metal
Let's say you wanted to enable ADC1.
In bare-metal C code, that looks like :

```  ADC1->CR2|=1;	```

Comparatively, LL looks like this :

``` LL_ADC_Enable(ADC1); ```

Quite a clear difference.
LL can also impact productivity. Let's say you wanted to set a baud rate for USART.

In bare-metal C code, that would look like this :

``` USART2->BRR = 0x00000D05; ```

Where this would set the Baud Rate to 115200 and the Frequency to 32MHz.

LL, on the other hand, does it like this :

``` LL_USART_SetBaudRate(USART2, SystemCoreClock, LL_USART_OVERSAMPLING_16, 9600); ```

Saves a bit of time and lets you customize the Baud Rate, Clock or Oversampling rate on the fly.

The full code snippet used for reading ADC temperatures, that was rewritten with LL, is here : https://github.com/D3SXX/STM32-Battery-Management/tree/feature/temperature-measurement/examples/lm35-LL

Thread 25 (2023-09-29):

MOSFET Board

SergiuPetrut, 2023-09-29:

Zhguye, 2023-09-29:
I'll write a long explanation text so when the mistake in the PCB happens it is easier to notice what I missed.

MOSFET (FDS6898AZ) Voltage value needs to be between +12V & +1.5V ( Gate-Source Voltage  & Gate Threshold Voltage). No drain voltage because drains are connected together and cells are connected to the source pins. Since the MOSFET we use is an N-type, we need a pull-down resistor from the gate.  (A P-type would use a pull-up resistor).

There are internal capacitors in the MOSFET that are important for the switching operations, like speed.
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
HOWEVER, NOTE THE VALUES ARE THE CAPACITANCE OF AREAS AND NOT THE CAPACITANCE OF SPECIFIC CAPACITORS.
My Japanese brethren have given a detailed explanation as usual
[https://toshiba.semicon-storage.com/info/application_note_en_20230209_AKX00063.pdf?did=13415](url)

I'm not sure if these internal capacitors are the reason the MOSFET behaves like a capacitor, however I think our MOSFET behaves like a voltage-controlled variable capacitor.

 Time values and other stuff are on the datasheet (useful stuff)?
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
The higher the gate charge, the higher the dissipation losses. :( Drain voltages also affect switching :(
Drain–Source On–Resistance should as small as possible
The switching time of a transistor is inversely proportional to the amount of current used to charge the gate.

MOSFET Gate Drivers exist. Their purpose is to safeguard the circuit from overcurrent (I think). I would say these aren't needed for our project because we aren't switching the MOSFET fast and often enough.

and I still think we need resistors, preferably 10k, from the gate to the source of every MOSFET. The reason being ESD. I don't think any group has yet to test a MOSFET so this problem has yet to occur.

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
This circuit layout is overthought if anything, I am not sure about all those pulldown resistors.
I'll try to make a second circuit just to make sure.

Zhguye, 2023-10-01:
I made it a bit nicer looking, fixed my mistakes, and added an idea of the MOSFET switching. (the red box indicates the switch logic, red box is purely visual)
The MOSFET circuit on the bottom is correct, it is connected drain to drain, which is why it looks mirrored. The most important part to focus on!
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

Zhguye, 2023-10-01:
This is my idea for the switching, pull-down for binary 1 and pull-up for binary 0.
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

Zhguye, 2023-10-01:
I think this is the proper circuit style.  C2/load at the bottom would be the negative polarity of the charger.  I believe this charging point will be the original input voltage.
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

The logic of the original bms:
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

Picture of the board:
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
The yellow box I drew contains resistors that are connected to the negative point of the battery therefore I would believe they are the resistors from gate to source??  But then it is interesting that I can't see the pull-down resistors.

TruthSeekerX, 2023-10-02:
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

TruthSeekerX, 2023-10-02:
Theoretical gate resistor could be 132R for 25mA Absolute Maximum Current of STM32L152RE IO pins. But we could use a bigger one, no need to go to the edge. For example 200ohm, would limit the current to 16.5mA

TruthSeekerX, 2023-10-02:
Pull down resister is good.

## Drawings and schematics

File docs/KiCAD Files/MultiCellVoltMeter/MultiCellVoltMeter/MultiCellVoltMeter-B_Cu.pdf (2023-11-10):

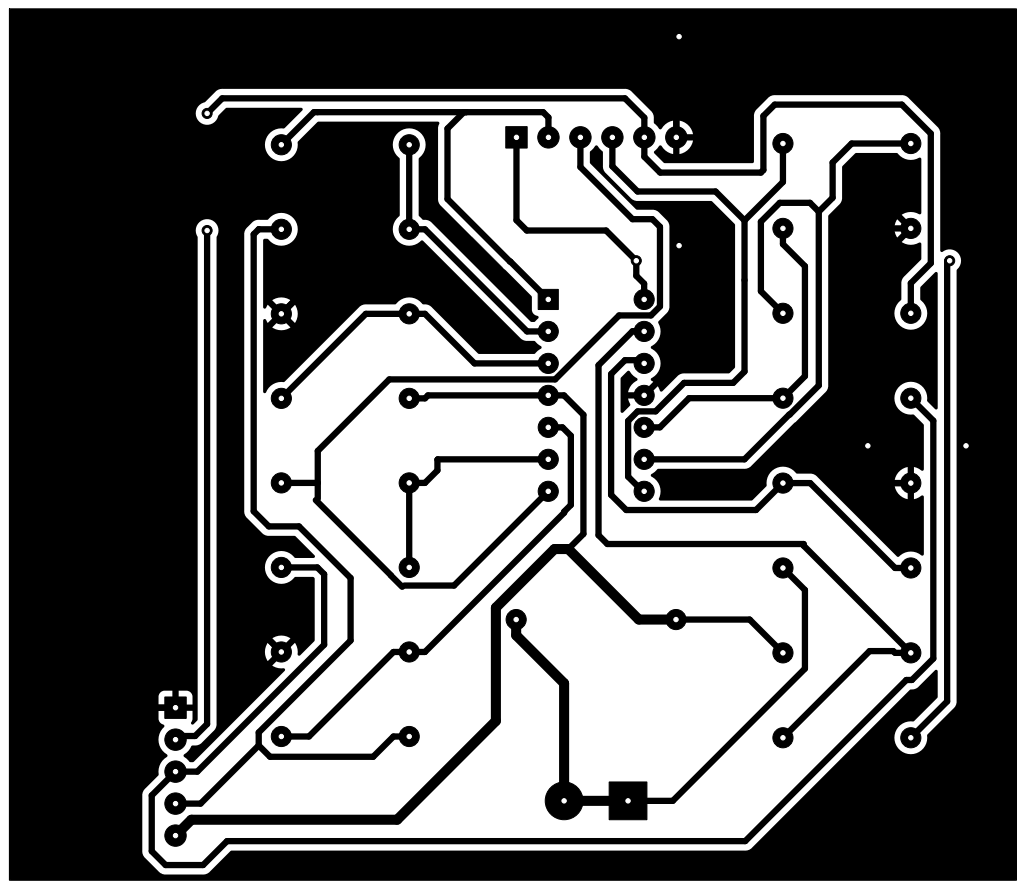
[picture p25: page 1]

Id: 1/1 Title: Multi cells voltage and current meter File: MultiCellVoltMeter.kicad_pcb Sheet: @Siyuan Xu

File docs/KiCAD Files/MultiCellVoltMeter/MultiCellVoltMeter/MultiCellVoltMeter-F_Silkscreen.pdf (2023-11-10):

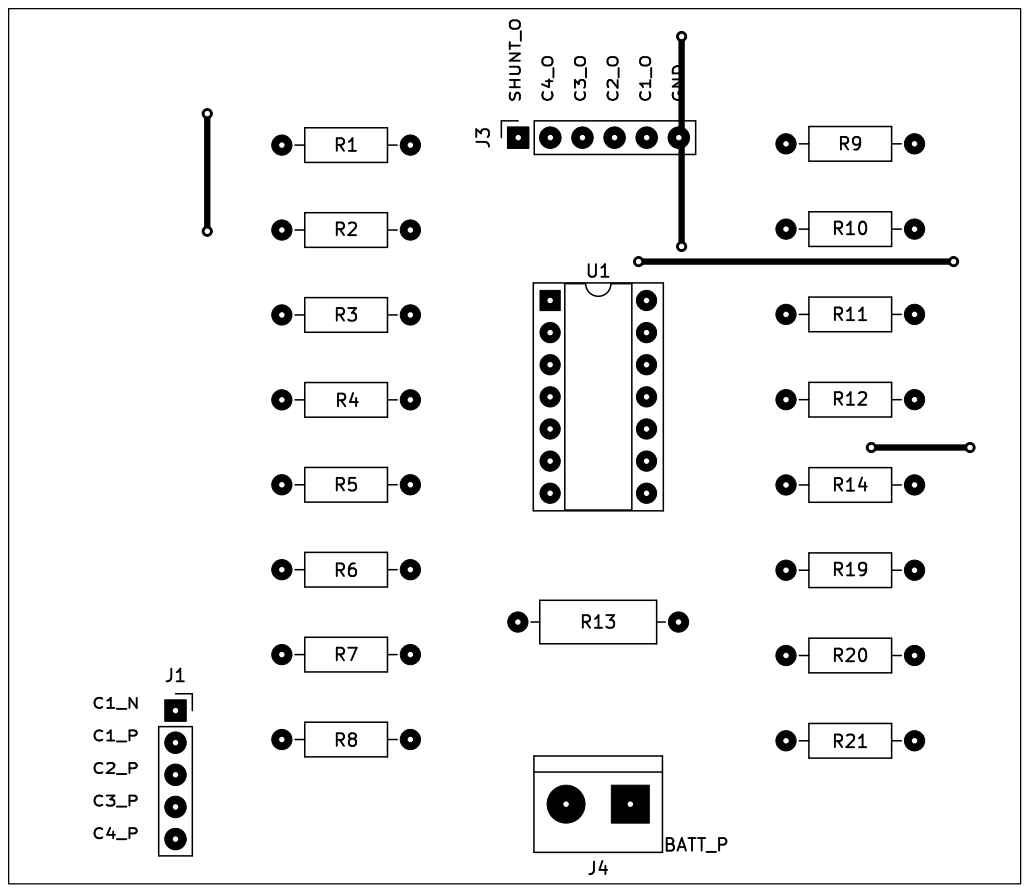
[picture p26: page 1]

Id: 1/1 Title: Multi cells voltage and current meter File: MultiCellVoltMeter.kicad_pcb Sheet: @Siyuan Xu

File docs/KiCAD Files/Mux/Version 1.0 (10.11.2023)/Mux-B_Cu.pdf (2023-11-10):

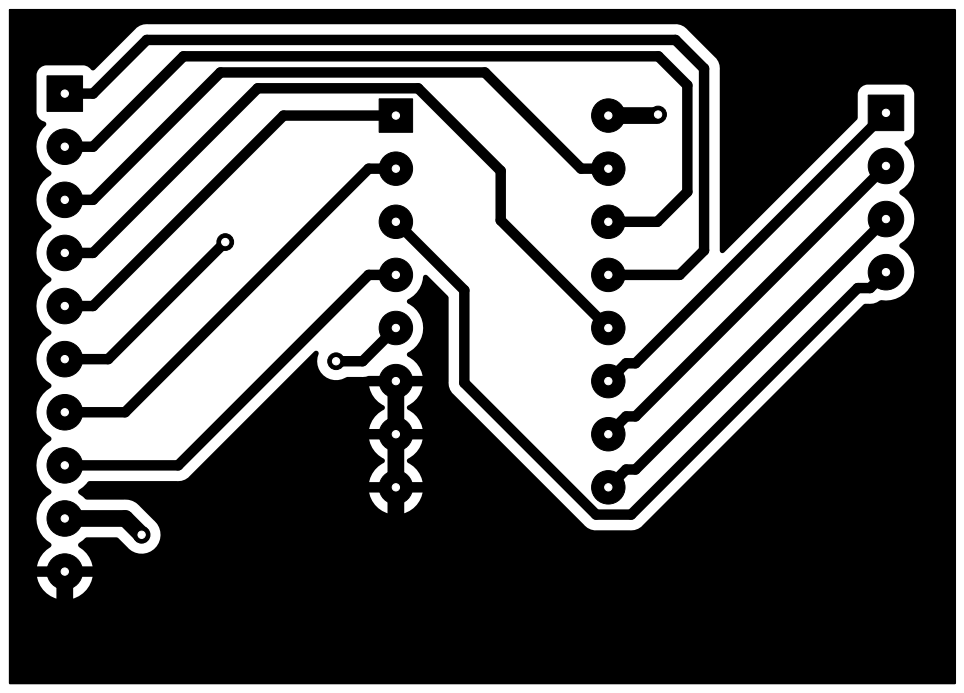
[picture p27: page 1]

Id: 1/1 Title: Multiplexer File: Mux.kicad_pcb Sheet: @Siyuan Xu

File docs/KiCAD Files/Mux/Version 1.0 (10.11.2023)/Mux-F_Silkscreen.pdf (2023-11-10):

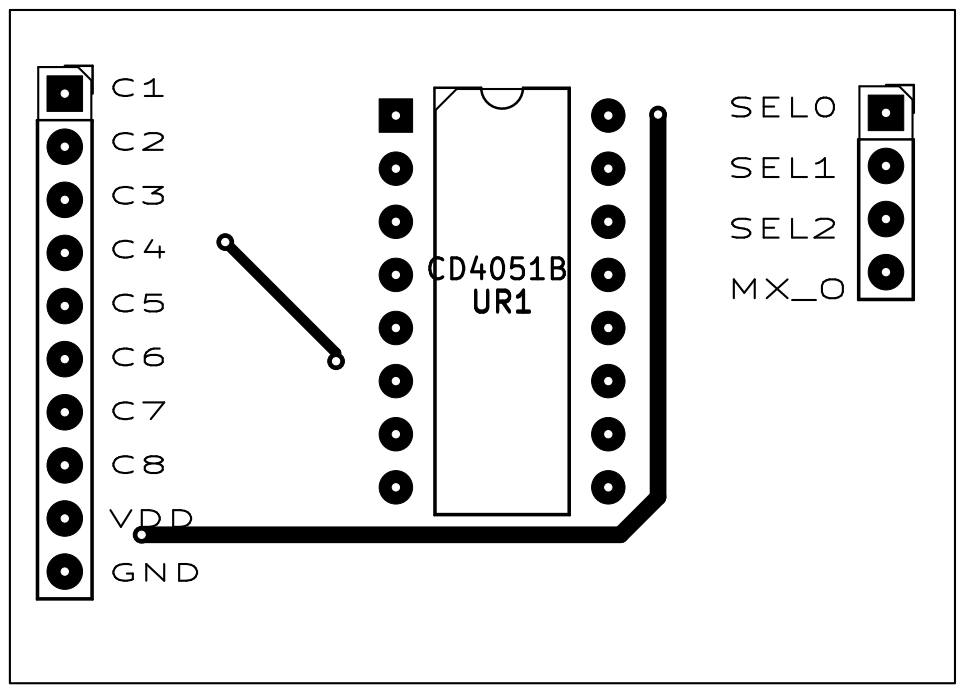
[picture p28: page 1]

Id: 1/1 Title: Multiplexer File: Mux.kicad_pcb Sheet: @Siyuan Xu

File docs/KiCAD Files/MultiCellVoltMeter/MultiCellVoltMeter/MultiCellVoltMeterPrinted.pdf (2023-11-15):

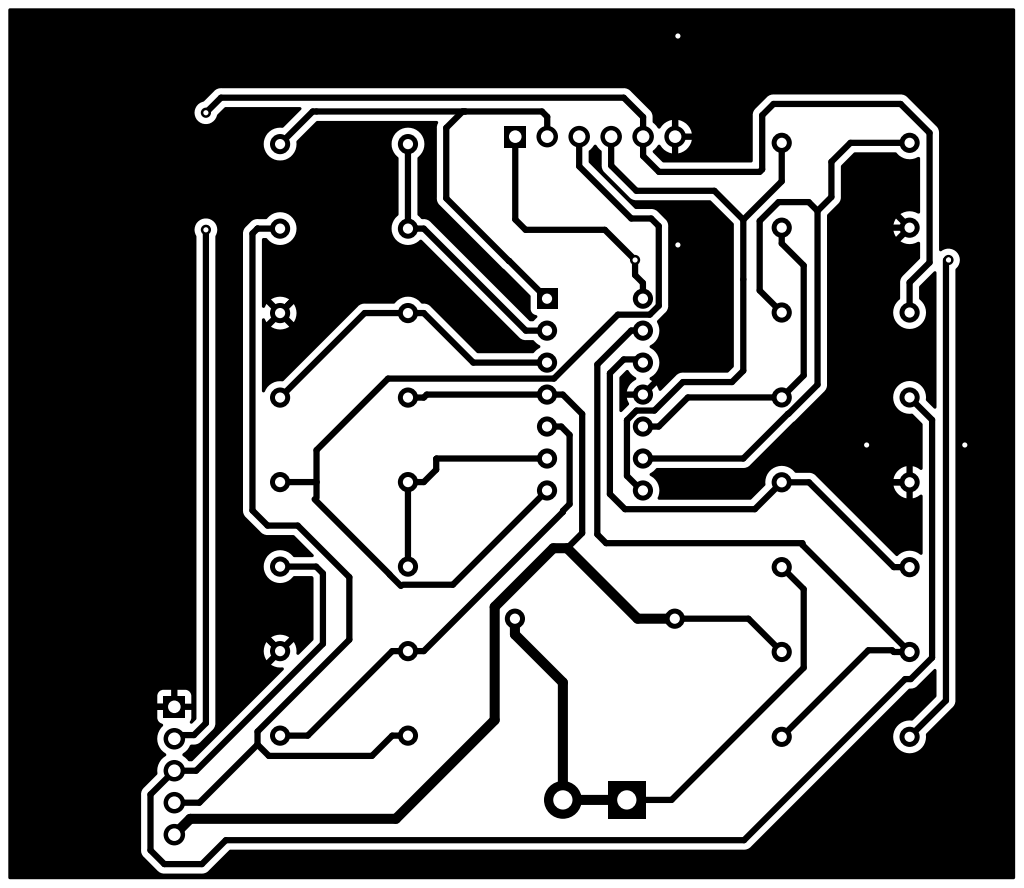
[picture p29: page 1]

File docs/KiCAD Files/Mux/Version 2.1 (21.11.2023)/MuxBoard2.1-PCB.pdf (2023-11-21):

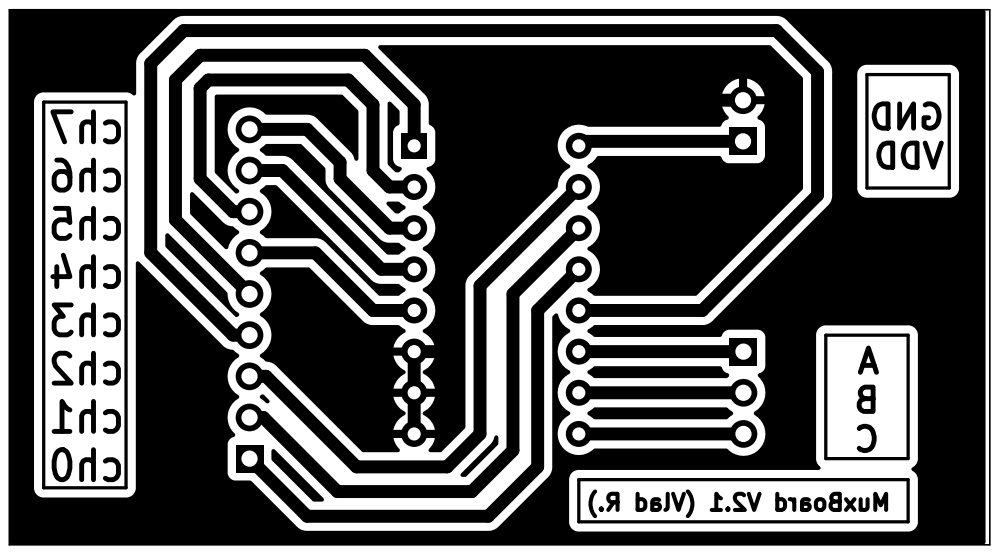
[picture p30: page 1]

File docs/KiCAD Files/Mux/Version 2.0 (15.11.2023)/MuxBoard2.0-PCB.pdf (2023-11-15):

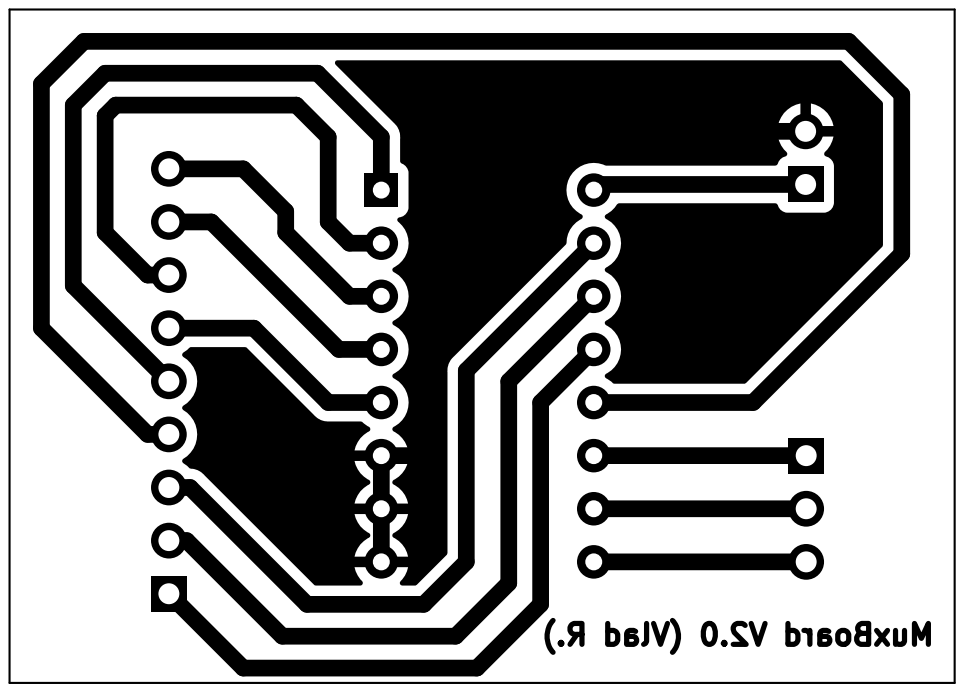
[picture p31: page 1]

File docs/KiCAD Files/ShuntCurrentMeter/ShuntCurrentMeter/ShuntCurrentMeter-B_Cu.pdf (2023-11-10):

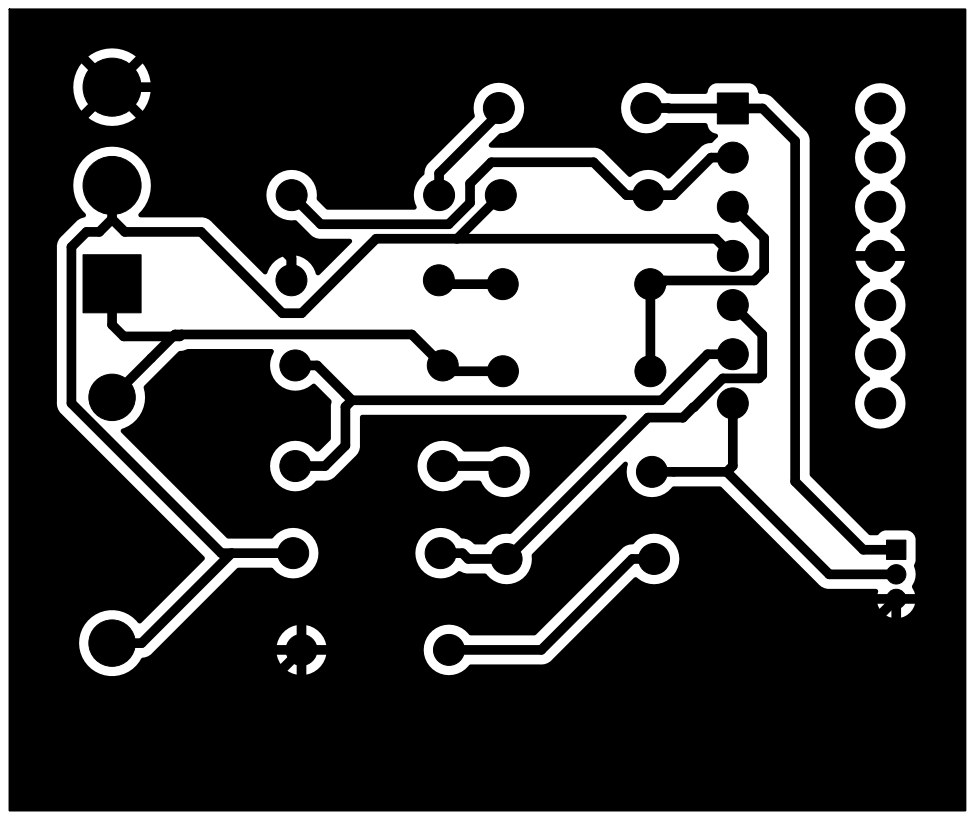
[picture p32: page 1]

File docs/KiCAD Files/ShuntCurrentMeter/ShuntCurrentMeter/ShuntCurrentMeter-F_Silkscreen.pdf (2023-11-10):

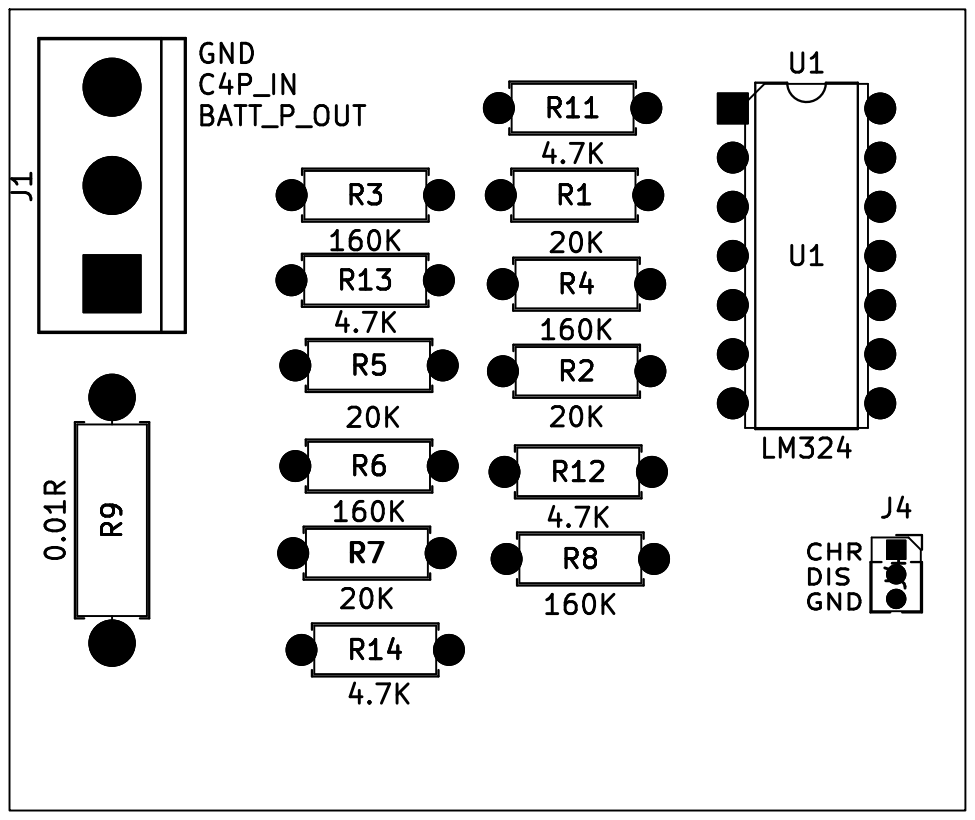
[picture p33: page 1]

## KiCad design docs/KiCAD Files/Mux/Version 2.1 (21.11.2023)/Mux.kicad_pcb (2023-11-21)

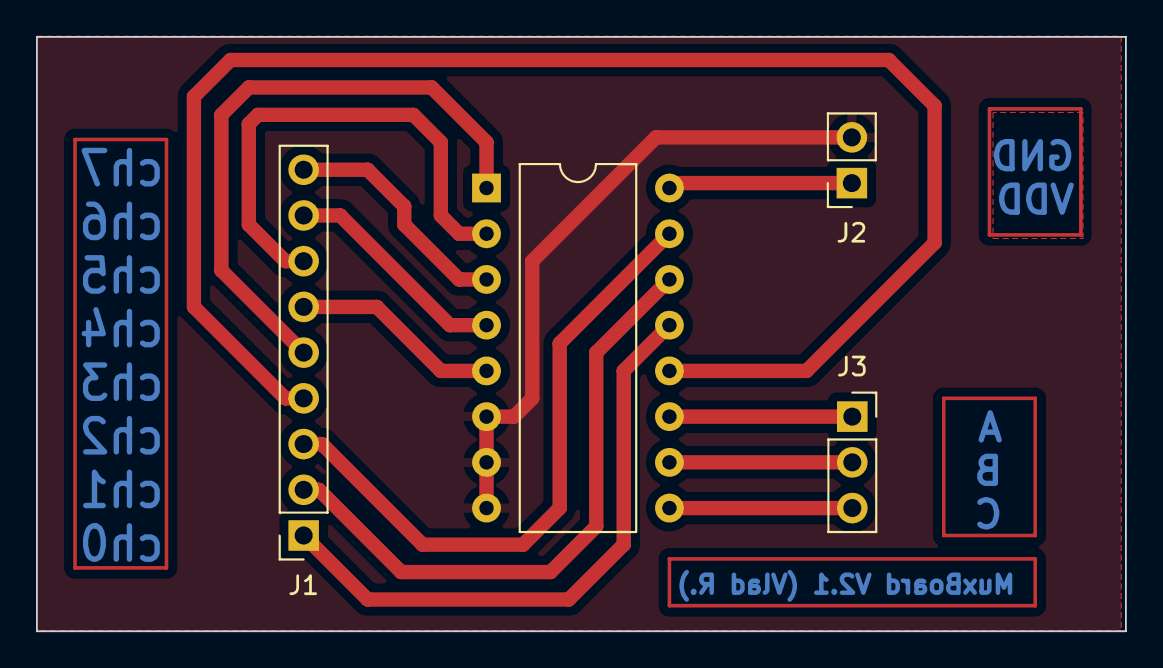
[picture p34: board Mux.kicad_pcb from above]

Board: 2 copper layers, 60.5 x 33.0 mm, 4 parts (0 on the bottom side), 14 nets.

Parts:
J1: Conn_01x09_Pin; SOCKET_1x9
J2: Conn_01x02_Socket; SOCKET_1x2
J3: Conn_01x03_Socket; SOCKET_1x3
UR1: CD4051B; DIP-16_W10.16mm

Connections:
0: J2.2, UR1.6 (INH), UR1.7 (VEE), UR1.8 (VSS)
/A: J3.1, UR1.11 (A)
/B: J3.2, UR1.10 (B)
/C: J3.3, UR1.9 (C)
/C0: J1.1, UR1.13 (X0)
/C1: J1.2, UR1.14 (X1)
/C2: J1.3, UR1.15 (X2)
/C3: J1.4, UR1.12 (X3)
/C4: J1.5, UR1.1 (X4)
/C5: J1.6, UR1.5 (X5)
/C6: J1.7, UR1.2 (X6)
/C7: J1.8, UR1.4 (X7)
/COM OUT/IN: J1.9, UR1.3 (X)
/VDD: J2.1, UR1.16 (VDD)

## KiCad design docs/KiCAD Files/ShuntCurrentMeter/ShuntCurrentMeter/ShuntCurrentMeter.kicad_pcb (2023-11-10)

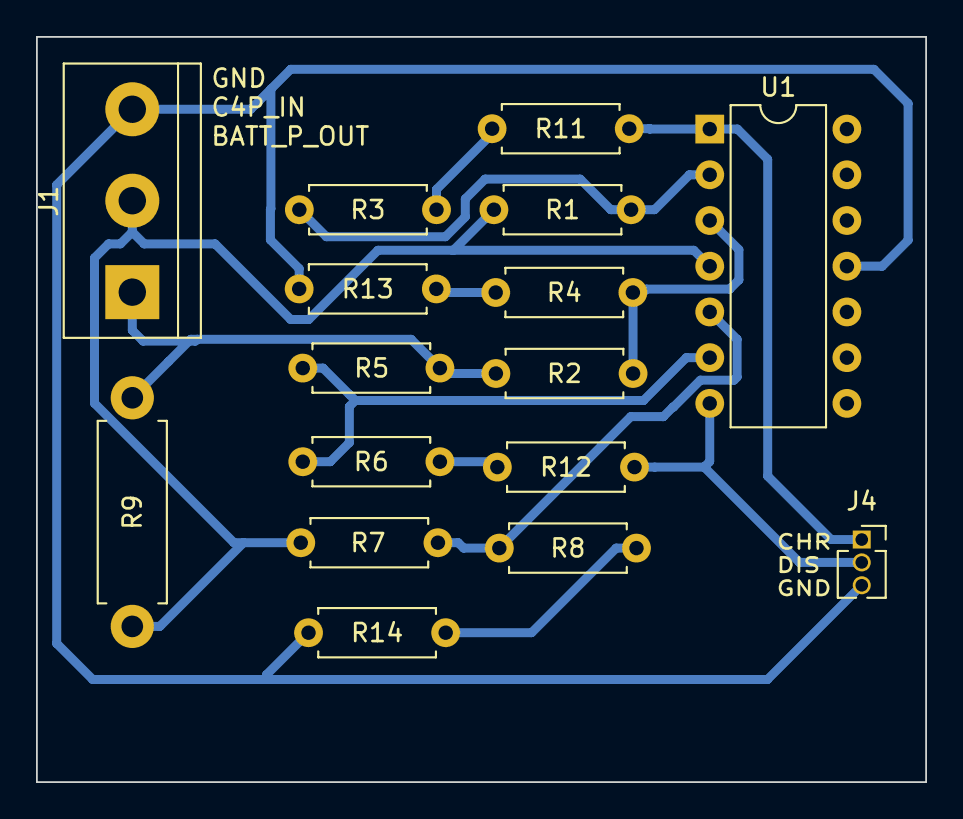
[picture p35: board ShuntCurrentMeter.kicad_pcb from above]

Board: 2 copper layers, 49.4 x 41.4 mm, 16 parts (0 on the bottom side), 13 nets.

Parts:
J1: Screw_Terminal_01x03; TerminalBlock_bornier-3_P5.08mm
J4: Conn_01x03_Socket; PinSocket_1x03_P1.27mm_Vertical
R1, R2, R5, R7: 20K; R_Axial_DIN0207_L6.3mm_D2.5mm_P7.62mm_Horizontal
R3, R4, R6, R8: 160K; R_Axial_DIN0207_L6.3mm_D2.5mm_P7.62mm_Horizontal
R9: 0.01R; R_Axial_DIN0411_L9.9mm_D3.6mm_P12.70mm_Horizontal
R11, R12, R13, R14: 4.7K; R_Axial_DIN0207_L6.3mm_D2.5mm_P7.62mm_Horizontal
U1: LM324; DIP14

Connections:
0: J1.3, J4.3, R13.2, R14.2, U1.11 (V-)
/BATT_P_OUT: J1.1, R2.1, R5.1, R9.1
/C4_P_IN: J1.2, R1.1, R7.1, R9.2, U1.4 (V+)
/CHG: J4.1, R11.2, U1.1
/DIS: J4.2, R12.2, U1.7
unnamed: R3.2, R11.1
unnamed: R6.2, R12.1
unnamed: R4.1, R13.1
unnamed: R8.2, R14.1
unnamed: R2.2, R4.2, U1.3 (+)
unnamed: R1.2, R3.1, U1.2 (-)
unnamed: R7.2, R8.1, U1.5 (+)
unnamed: R5.2, R6.1, U1.6 (-)

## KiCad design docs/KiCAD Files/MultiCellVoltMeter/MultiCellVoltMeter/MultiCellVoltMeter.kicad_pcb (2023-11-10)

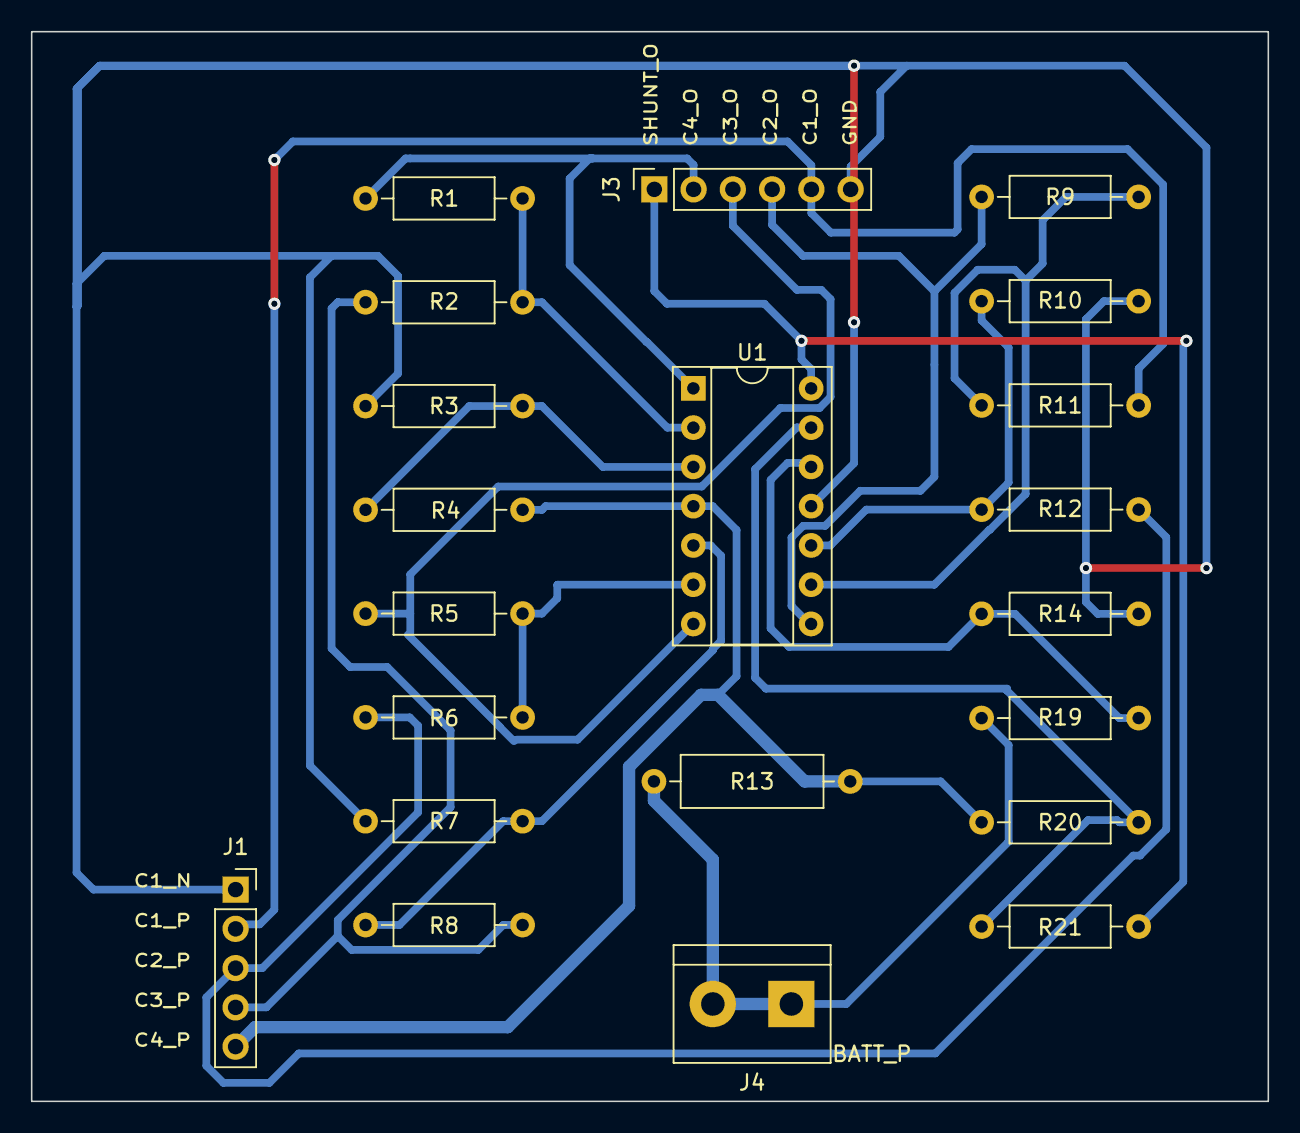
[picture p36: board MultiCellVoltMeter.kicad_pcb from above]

Board: 2 copper layers, 80.0 x 69.2 mm, 21 parts (0 on the bottom side), 18 nets.

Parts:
J1: Conn_01x05_Socket; SOCKET_1x5
J3: Conn_01x06_Socket; SOCKET_1x6
J4: Screw_Terminal_01x02; TerminalBlock_bornier-2_P5.08mm
R1, R3, R5, R7, R9, R10: 16K; R_Axial_DIN0207_L6.3mm_D2.5mm_P10.16mm_Horizontal
R2, R4, R6, R8, R11, R12, R19, R20: 20K; R_Axial_DIN0207_L6.3mm_D2.5mm_P10.16mm_Horizontal
R13: 0.01; R_Axial_DIN0309_L9.0mm_D3.2mm_P12.70mm_Horizontal
R14, R21: 160K; R_Axial_DIN0207_L6.3mm_D2.5mm_P10.16mm_Horizontal
U1: LM324; DIP-14_W7.62mm_Socket

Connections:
0: J1.1, J3.6, R3.1, R7.1, R10.1, R14.2, U1.11 (V-)
/BATT_P_OUT: J4.1, J4.2, R13.2, R19.1
/C1_OUT: J1.2, J3.5, R11.2
/C2_OUT: J3.4, R9.1, U1.8
/C2_P: J1.3, R6.2, R12.2
/C3_OUT: J3.3, R5.1, U1.7
/C3_P: J1.4, R2.1, R8.2
/C4_OUT: J3.2, R1.2, U1.1
/C4_P: J1.5, R4.2, R13.1, R20.1, U1.4 (V+)
/SHUNT_OUT: J3.1, R21.2, U1.14
unnamed: R3.2, R4.1, U1.3 (+)
unnamed: R1.1, R2.2, U1.2 (-)
unnamed: R7.2, R8.1, U1.5 (+)
unnamed: R5.2, R6.1, U1.6 (-)
unnamed: R10.2, R12.1, U1.10 (+)
unnamed: R9.2, R11.1, U1.9 (-)
unnamed: R14.1, R19.2, U1.12 (+)
unnamed: R20.2, R21.1, U1.13 (-)

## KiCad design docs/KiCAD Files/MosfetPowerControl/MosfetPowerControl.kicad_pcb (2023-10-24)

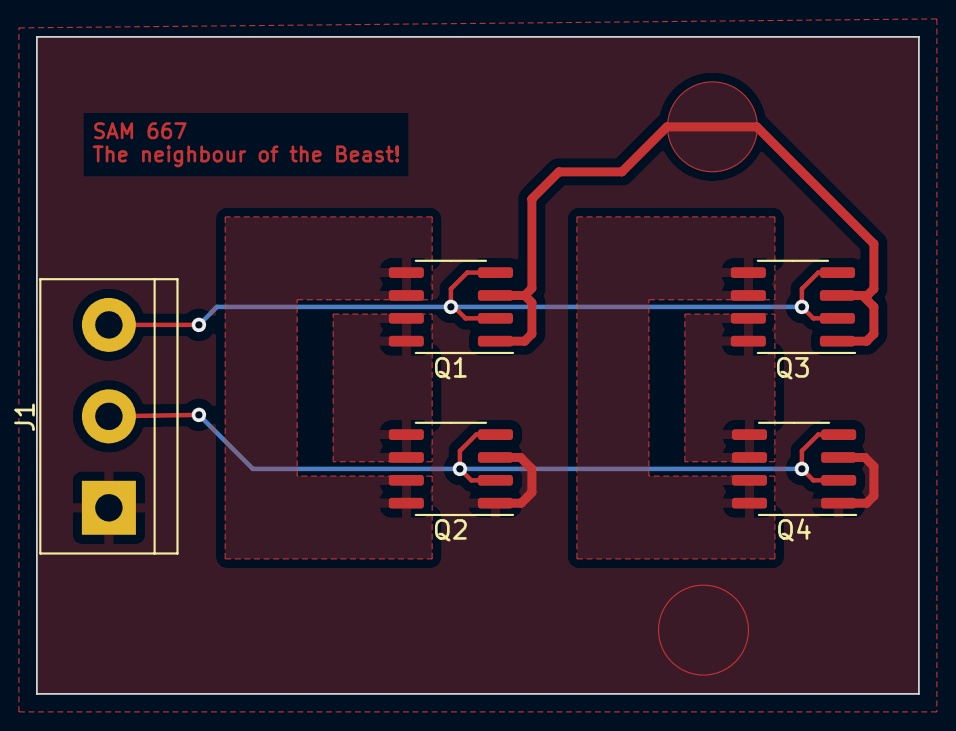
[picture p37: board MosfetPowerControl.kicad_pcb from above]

Board: 2 copper layers, 49.0 x 36.5 mm, 5 parts (0 on the bottom side), 8 nets.

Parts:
J1: Screw_Terminal_01x03; TM_BLOCK_3P
Q1, Q2, Q3, Q4: FDS6898A; SOIC-8_3.9x4.9mm_P1.27mm

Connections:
/D1: Q1.7 (D1), Q1.8 (D1), Q2.5 (D2), Q2.6 (D2)
/D2: Q1.5 (D2), Q1.6 (D2), Q2.7 (D1), Q2.8 (D1)
/D3: Q3.7 (D1), Q3.8 (D1), Q4.5 (D2), Q4.6 (D2)
/D4: Q3.5 (D2), Q3.6 (D2), Q4.7 (D1), Q4.8 (D1)
/G1: J1.3, Q1.2 (G1), Q1.4 (G2), Q3.2 (G1), Q3.4 (G2)
/G2: J1.2, Q2.2 (G1), Q2.4 (G2), Q4.2 (G1), Q4.4 (G2)
/PSU_N: Q1.1 (S1), Q1.3 (S2), Q3.1 (S1), Q3.3 (S2)
GND: J1.1, Q2.1 (S1), Q2.3 (S2), Q4.1 (S1), Q4.3 (S2)

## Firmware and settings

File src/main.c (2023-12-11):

#include "STM32L1xx_LL_Driver.h"
#include "adc.h"
#include "battery_manager.h"
#include "iwdg.h"
#include "modbus_rtu.h"
#include "modbus_rtu_func_4.h"
#include "mosfet_control.h"
#include "mux.h"
#include "stdbool.h"
#include "sysclock_config.h"
#include "timer.h"
#include "usart_config.h"
#include "utils.h"

#if (MOC_ADC_EN > 0)
#include "moc_adc_read.h"
#endif

#if (DEBUG_CONSOLE_EN > 0u)
#include "stdio.h"
#endif

/* Private flags  */
#define MODBUS_REQUEST       0x01U
#define ADC_READ_CURRENT     0x02U
#define ADC_READ_TEMPERATURE 0x04U
#define ADC_READ_VOLTS       0x08U
#define ADC_READ_ALL         0x0EU
#define DMA1_ERROR           0x8000U

uint16_t subroutine_flag  = 0x00;
bool     dma1_ch5_tc_flag = false;  // DMA1 ch5 Transmite complete flag

/* Private macro */
#define ARRAY_LEN(x) (sizeof(x) / sizeof((x)[0]))

/* Private variables */
uint8_t usart1_rx_dma_buffer[USART1_RX_DMA_BUFFER_SIZE];
#if (DEBUG_CONSOLE_EN > 0u)
uint8_t usart2_rx_dma_buffer[USART2_RX_DMA_BUFFER_SIZE];
#endif

/* Private function prototypes  */
static inline void LED2_init(void) {
    RCC->AHBENR |= 1;       // GPIOA ABH bus clock ON. p154
    GPIOA->MODER |= 0x400;  // GPIOA pin 5 to output. p184
}

void Configure_DebugPin(uint32_t debug_pin) {
    LL_AHB1_GRP1_EnableClock(LL_AHB1_GRP1_PERIPH_GPIOA);
    LL_GPIO_SetPinMode(GPIOA, debug_pin, LL_GPIO_MODE_OUTPUT);
}

void modbus_routine();
void read_current_routine(void);
void read_temperature_routine(void);
void read_cell_voltage_routine(void);
void TIM2_IRQ_handler(void);
void usart1_rx_dma_frame_oversize_check();

/* Main routine */
int main(void) {
    __disable_irq();
    SystemClock_Config();
    systick_init(1000);  // set SysTick frequency to 1000Hz
    USART1_dma_init();
#if (DEBUG_CONSOLE_EN > 0u)
    USART2_dma_init();
#endif
    IWDG_init();
    adc_init();
    mux_init();
    mosfet_control_init();
    LED2_init();
    timer2_init();
    timer2_start(1000, 1000);
    LL_GPIO_SetPinMode(GPIOA, LL_GPIO_PIN_8, LL_GPIO_MODE_OUTPUT);  // config a debug pin on GPIO
#if (DEBUG_CONSOLE_EN > 0u)
    debug_console("App started...\r\n");
#endif
    __enable_irq();

    while (1) {
        IWDG_feed();

        if (subroutine_flag & ADC_READ_TEMPERATURE) {
            read_temperature_routine();
        }
        if (subroutine_flag & ADC_READ_CURRENT) {
            read_current_routine();
        }
        if (subroutine_flag & ADC_READ_VOLTS) {
            read_cell_voltage_routine();
        }
        if (subroutine_flag & MODBUS_REQUEST) {
            modbus_routine();
            usart1_rx_dma_frame_oversize_check();
            subroutine_flag &= ~MODBUS_REQUEST;
        }
        if (subroutine_flag & DMA1_ERROR) {
            USART1_RX_DMA_Buffer_Reset();
            DMA1_Channel15_Reload();
            subroutine_flag &= ~DMA1_ERROR;  // Reset DMA1_ERROR
        }
        // LL_GPIO_TogglePin(GPIOA, LL_GPIO_PIN_5);
    }
}

/**
 * \brief   DMA1 channel5 interrupt handler for USART1 RX
 * \author  Siyuan Xu,
 * \details If modbus request message length is great than 8 bytes
 */
void usart1_rx_dma_frame_oversize_check(void) {
    if (!dma1_ch5_tc_flag && usart1_rx_dma_buffer[0] != 0) {
        subroutine_flag |= DMA1_ERROR;
    }
}

/* Interrupt handlers here */
void SysTick_Handler(void) {
    // Debug PIN PA8
    // LL_GPIO_TogglePin(GPIOA, LL_GPIO_PIN_8);
}

void TIM2_IRQHandler(void) {
    // Handle a timer 'update' interrupt event
    if (TIM2->SR & TIM_SR_UIF) {
        TIM2->SR &= ~(TIM_SR_UIF);
        if (!(subroutine_flag & MODBUS_REQUEST)) {  // prevent reading during modbus request.
            subroutine_flag |= ADC_READ_ALL;
        }
    }
    LL_GPIO_TogglePin(GPIOA, LL_GPIO_PIN_5);
}

void modbus_routine(void) {
    if (MODBUS_RTU_ERR_SUCCESS !=
        modbusRtu_AddressValidation(usart1_rx_dma_buffer[SLAVE_ADDRESS])) {
#if (DEBUG_CONSOLE_EN > 0u)
        char debug_msg[DBUG_MSG_LEN];
        snprintf(debug_msg, DBUG_MSG_LEN, "SlaveAddr:%#x\r\n", usart1_rx_dma_buffer[SLAVE_ADDRESS]);
        debug_console("Not my address, discard the frame!\r\n");
#endif
    } else {
        modbusRtu_ParseRequest(usart1_rx_dma_buffer);
#if (DEBUG_CONSOLE_EN > 0u)
        debug_console("My address, Run Modbus_ParseRequest()!\r\n");
#endif
    }
    // TBD - start usart1_watchdog(USART1_RX_Buffer_Reset)
    subroutine_flag &= ~MODBUS_REQUEST;  // disable the flag
    dma1_ch5_tc_flag = false;
    USART1_RX_DMA_Buffer_Reset();
    DMA1_Channel15_Reload();
}

void read_current_routine(void) {
    mux_set(MUX_SEL_CURRENT);
    uint16_t adc_value = 0;
    uint16_t current   = 0;
#if (MOC_ADC_EN > 0)
    static uint16_t moc_current_adc = 0;
    adc_value                       = moc_current_adc;
    moc_current_adc += 200;
    moc_current_adc = moc_current_adc > 990 ? 0 : moc_current_adc;
#else
    adc_value = adc_read(ADC_INPUT_BATT_CURRENT);
#endif
    current                                 = adc_convert_batt_current(adc_value);
    modbus_registers[REG_ADDR_BATT_CURRENT] = current;
    battery_manager_current_check((int16_t)current);
    subroutine_flag &= ~ADC_READ_CURRENT;
}

void read_temperature_routine(void) {
#if (MOC_ADC_EN > 0)
    static uint16_t moc_temp_adc = 0;
    moc_adc_set(moc_temp_adc);
    moc_temp_adc += 100;
    moc_temp_adc = moc_temp_adc > 4095 ? 0 : moc_temp_adc;
#endif
    int32_t  temp_int = 0;
    int32_t temp_pos = 0;
    int32_t temp_neg = 0;
#if (MOC_ADC_EN > 0)
    temp_int = adc_convert_batt_temp(moc_adc_read(0));
#else
    temp_pos = (int32_t)adc_convert_batt_temp(adc_read(ADC_INPUT_BATT_TEMP_P));
    temp_neg = (int32_t)adc_convert_batt_temp(adc_read(ADC_INPUT_BATT_TEMP_N));
    temp_int = temp_pos - temp_neg;
#endif
    modbus_registers[REG_ADDR_BATT_TEMP] =
        (uint16_t)temp_int;  // explicitly convert int16_t to uint16_t. Modbus client should convert
                             // it back to int16_t
    double temp_double = (double)temp_int / 10.0;
    battery_manager_temperature_check(temp_double);
    subroutine_flag &= ~ADC_READ_TEMPERATURE;
}

void read_cell_voltage_routine(void) {
#if (MOC_ADC_EN > 0)
    static uint16_t moc_volt_adc = 2900;
    moc_adc_set(moc_volt_adc);
    moc_volt_adc += 100;
    moc_volt_adc = moc_volt_adc > 4095 ? 2980 : moc_volt_adc;
#endif
    mux_set(MUX_SEL_CELL1);
    uint16_t voltage   = 0;
    uint16_t adc_value = 0;
#if (MOC_ADC_EN > 0)
    voltage = adc_convert_cell_voltage(moc_adc_read(1));
#else
    adc_value = adc_read(ADC_INPUT_CELL_VOLTAGE);
    adc_value = adc_read(ADC_INPUT_CELL_VOLTAGE);
    voltage   = adc_convert_cell_voltage(adc_value);
#endif
    modbus_registers[REG_ADDR_CELL1_VOLT] = voltage;
    battery_manager_cell_voltage_check(0, voltage);

    mux_set(MUX_SEL_CELL2);
#if (MOC_ADC_EN > 0)
    voltage = adc_convert_cell_voltage(moc_adc_read(2));
#else
    adc_value = adc_read(ADC_INPUT_CELL_VOLTAGE);
    voltage   = adc_convert_cell_voltage(adc_value);
#endif
    modbus_registers[REG_ADDR_CELL2_VOLT] = voltage;
    battery_manager_cell_voltage_check(1, voltage);

    mux_set(MUX_SEL_CELL3);
#if (MOC_ADC_EN > 0)
    voltage = adc_convert_cell_voltage(moc_adc_read(3));
#else
    adc_value = adc_read(ADC_INPUT_CELL_VOLTAGE);
    voltage   = adc_convert_cell_voltage(adc_value);
#endif
    modbus_registers[REG_ADDR_CELL3_VOLT] = voltage;
    battery_manager_cell_voltage_check(2, voltage);

    mux_set(MUX_SEL_CELL4);
#if (MOC_ADC_EN > 0)
    voltage = adc_convert_cell_voltage(moc_adc_read(4));
#else
    adc_value = adc_read(ADC_INPUT_CELL_VOLTAGE);
    voltage   = adc_convert_cell_voltage(adc_value);
#endif
    modbus_registers[REG_ADDR_CELL4_VOLT] = voltage;
    battery_manager_cell_voltage_check(3, voltage);
    subroutine_flag &= ~ADC_READ_VOLTS;
}

/**
 * \brief   DMA1 channel5 interrupt handler for USART1 RX
 * \author  Siyuan Xu,
 */
void DMA1_Channel5_IRQHandler(void) {
    /* Check half-transfer complete interrupt */
    // TBD-REMOVE HALF-TRANSFER INTERRUPT
    if (DMA1->ISR & DMA_ISR_HTIF5) {
#if (DEBUG_CONSOLE_EN > 0u)
        debug_console("USART1 DMA half-transfer interrupt!\r\n");
#endif
        DMA1->IFCR |= DMA_IFCR_CHTIF5; /*!< Channel 5 Half Transfer clear */
    }

    /* Check transfer-complete interrupt */
    if (DMA1->ISR & DMA_ISR_TCIF5) {
#if (DEBUG_CONSOLE_EN > 0u)
        debug_console("USART1 DMA transfer-complete interrupt!\r\n");
#endif
        dma1_ch5_tc_flag = true;
        subroutine_flag |= MODBUS_REQUEST;  // enable the flag
        DMA1->IFCR |= DMA_IFCR_CTCIF5;      /*!< Channel 5 Transfer Complete clear */
    }
}

/**
 * \brief   USART1 global interrupt handler
 * \author  Siyuan xu, e2101066@edu.vamk.fi, Feb.2023
 */
void USART1_IRQHandler(void) {
    uint32_t status = USART1->SR;
    uint8_t  data __attribute__((unused));

    /* Check for Read Data Register Not Empty interrupt */
    if (status & USART_SR_RXNE) {
#if (DEBUG_CONSOLE_EN > 0u)
        debug_console("USART1 Read Data Register Not Empty!\r\n");
#endif
    }
    /* Check for IDLE line interrupt */
    if (status & USART_SR_IDLE) {
#if (DEBUG_CONSOLE_EN > 0u)
        debug_console("USART1 Idle-line interrupt!\r\n");
#endif
        // TBD - Stop usart1_watchdog
        if (dma1_ch5_tc_flag == true) {
            data = USART1->DR; /* Clear IDLE line flag */
        } else {
            // Error condition when USART1 DMA transmit complete flag is false and IDLE line
            // interrupt fires, reset DMA1 and buffer
            subroutine_flag |= DMA1_ERROR;
            data = USART1->DR; /* Clear IDLE line flag */
#if (DEBUG_CONSOLE_EN > 0u)
            debug_console(
                "Error!"
                "IDLE line detected, but dma transmition complete flag is FALSE!\r\n"
                "Received modbus frame length is lesser than expected.\r\n");
#endif
        }
    }
    /* Check Tranmission complete interrupt */
    if (status & USART_SR_TC) {
        if (!dma1_ch5_tc_flag && usart1_rx_dma_buffer[0] != 0) {
            subroutine_flag |= DMA1_ERROR;
#if (DEBUG_CONSOLE_EN > 0u)
            debug_console(
                "ERROR! Transmition complete. But USART1_RX buffer is not empty."
                "Received modbus frame length is greater than expected.\r\n");
#endif
        }
    }
}

/**
 * \brief   DMA1 channel6 interrupt handler for USART2 RX
 * \author  Siyuan xu, e2101066@edu.vamk.fi, Feb.2023
 */
void DMA1_Channel6_IRQHandler(void) {
    // TBD REMOVE DMA1_Channel6
    /* Check half-transfer complete interrupt */
    if (DMA1->ISR & DMA_ISR_HTIF6) {
#if (DEBUG_CONSOLE_EN > 0u)
        debug_console("USART2 DMA half-transfer interrupt!\r\n");
#endif
        DMA1->IFCR |= DMA_IFCR_CHTIF6; /*!< Channel 6 Half Transfer clear */
        USART2_send_data(usart2_rx_dma_buffer, USART2_RX_DMA_BUFFER_SIZE);
    }

    /* Check transfer-complete interrupt */
    if (DMA1->ISR & DMA_ISR_TCIF6) {
#if (DEBUG_CONSOLE_EN > 0u)
        debug_console("USART2 DMA transfer-complete interrupt!\r\n");
#endif
        DMA1->IFCR |= DMA_IFCR_CTCIF6; /*!< Channel 6 Transfer Complete clear */
        USART2_send_data(usart2_rx_dma_buffer, USART2_RX_DMA_BUFFER_SIZE);
    }
}

/**
 * \brief   USART2 global interrupt handler
 * \author  Siyuan xu, e2101066@edu.vamk.fi, Feb.2023
 */
void USART2_IRQHandler(void) {
    uint32_t status = USART2->SR;
    uint8_t  data __attribute__((unused));
    /* Check for IDLE line interrupt */
    if (status & USART_SR_IDLE) {
#if (DEBUG_CONSOLE_EN > 0u)
        debug_console("USART2 Idle-line interrupt!\r\n");
#endif
        data = USART2->DR; /* Clear IDLE line flag */
        USART2_send_data(usart2_rx_dma_buffer, USART2_RX_DMA_BUFFER_SIZE);
        DMA1_Channel16_Reload();
    }
}

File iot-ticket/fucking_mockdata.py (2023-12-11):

#lib
import json
import time
from iotticket.models import device
from iotticket.models import criteria
from iotticket.models import deviceattribute
from iotticket.models import datanodesvalue
from iotticket.client import Client
import minimalmodbus
import numpy as np

#main
# modbus_read fuction code 04 is added
def modbus_read_input_register(register_addr):
    # Define the serial port and communication parameters
    SERIAL_PORT = 'com6'  # Adjust this to your serial port
    SLAVE_ADDRESS = 5  # Adjust this to your specific Modbus device's address
    BAUD_RATE = 115200

    # Create a minimalmodbus instrument instance
    instrument = minimalmodbus.Instrument(SERIAL_PORT, SLAVE_ADDRESS)
    instrument.serial.baudrate = BAUD_RATE
    instrument.serial.timeout = 1  # Adjust the timeout as needed

    try:
        # Read a holding register (e.g., register address 0x0001)
        register_value = instrument.read_register(register_addr, functioncode=4)
        # Print the value
        print(f"Value at register {register_addr}: {register_value}")
    except Exception as e:
        print(f"Error: {str(e)}")
    finally:
        # Close the serial connection
        instrument.serial.close()
    
    return register_value


data = json.load(open("iot-ticket\Config.json"))
username = data["username"]
password = data["password"]
deviceId = data["deviceId"]
baseurl = data["baseurl"]
iotClient = Client(baseurl, username, password)

voltage = 2.7
current = 2.5
temperature = -20.5

cell_1_voltage = datanodesvalue(name="cell1_voltage", dataType="double", unit="Volts")
cell_1_voltage.set_path("cell1_volt")
cell_2_voltage = datanodesvalue(name="cell2_voltage", path="/cell2_volt", dataType="double", unit="Volts")
cell_3_voltage = datanodesvalue(name="cell3_voltage", path="/cell3_volt", dataType="double", unit="Volts")
cell_4_voltage = datanodesvalue(name="cell4_voltage", path="/cell4_volt", dataType="double", unit="Volts")
battery_current = datanodesvalue(name="battery_current", path="/batt_current", dataType="double", unit="Amps")
battery_temp = datanodesvalue(name="battery_temperature", dataType="double", unit="C")
battery_temp.set_path("batt_temp")

voltage_data_collection = list()
voltage_data_collection.append(cell_1_voltage)
voltage_data_collection.append(cell_2_voltage)
voltage_data_collection.append(cell_3_voltage)
voltage_data_collection.append(cell_4_voltage)


while True:
    # write datanode demo
    # some mock data here
    startRegisterAddress = 0
    for voltageData in voltage_data_collection:
        voltage = modbus_read_input_register(startRegisterAddress)/1000
        voltageData.set_value(voltage)
        voltageData.set_timestamp(int(round(time.time() * 1000)))
        startRegisterAddress = startRegisterAddress + 1
        print(f"{voltageData.name}: {voltageData.v} {voltageData.unit}")
        # if voltageData.name == "cell1_voltage":
        #     voltageData.set_value(modbus_read_voltage())
        #     voltageData.set_timestamp(int(round(time.time() * 1000)))
        # else:
        #     voltageData.set_value(voltage)
        #     voltageData.set_timestamp(int(round(time.time() * 1000)))
    # battery_current.set_value(current)
    # battery_current.set_timestamp(int(round(time.time() * 1000)))
    # battery_temp.set_value(temperature)
    # battery_temp.set_timestamp(int(round(time.time() * 1000)))

    current = modbus_read_input_register(startRegisterAddress)/1000
    battery_current.set_value(current)
    battery_current.set_timestamp(int(round(time.time() * 1000)))
    startRegisterAddress = startRegisterAddress + 1
    print(f"{battery_current.name}: {battery_current.v} {battery_current.unit}")

    temperature_int = modbus_read_input_register(startRegisterAddress)
    temperature_uint16 = np.uint16(temperature_int)
    temperature_int16 = np.int16(temperature_uint16)
    temperature_double = temperature_int16 / 10

    battery_temp.set_value(temperature_double)
    battery_temp.set_timestamp(int(round(time.time() * 1000)))
    print(f"{battery_temp.name}: {battery_temp.v} {battery_temp.unit}")
    # iotDataCollection = voltage_data_collection.copy()
    # iotDataCollection.append(battery_current)
    # iotDataCollection.append(battery_temp)
    
    print(iotClient.writedata(deviceId, *voltage_data_collection))
    print(iotClient.writedata(deviceId, battery_current))
    print(iotClient.writedata(deviceId, battery_temp))
    
    # voltage += 0.1
    # current += 1
    # temperature += 5

    # voltage = 2.7 if voltage >= 3.9 else voltage
    # current = 2.5 if current >= 40 else current
    # temperature = -20.5 if temperature >= 50 else temperature

    print("sleeping 5s...")
    time.sleep(5)

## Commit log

2023-09-29 Update main.c
    Make a delay after mux channel switch
    Add temp
    Improve comments
2023-09-29 Added KiCAD schemas
    [EmbSysProject.kicad_pcb, EmbSysProject.kicad_sch, VoltageReader.kicad_pcb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]
2023-10-04 read from stm32 via modbus was added
2023-10-04 MosfetPowerControl and MultiCellBatteryMeter
2023-10-09 Better circuit design for MPC
2023-10-09 Better circuit design for MCB
2023-10-09 Better MPC sim circuit
2023-10-09 better error handling for wrong size modbus frame
    [main.c]
2023-10-24 MosfetPowerControl PCB and Simu
    [MosfetPowerControl.kicad_pcb, MosfetPowerControl.kicad_sch]
2023-10-25 move modbus_routine out from interrupt to main
2023-10-26 Negative temperature meas. and ADC optimization
2023-10-26 dma transmission error handling Too long/Too shrot
    [main.c]
2023-10-26 Added timer2
2023-10-26 added adc
2023-10-27 better documentation for lib timer
2023-11-10 Multiplexer Schema and PCB
    [Mux.kicad_pcb, Mux.kicad_sch]
2023-11-10 mosfet libs
2023-11-10 current meter schema
    [ShuntCurrentMeter.kicad_sch]
2023-11-10 lm324 lib and ngspice quad model
    [lmx24_lm2902.dsn]
2023-11-10 current meter pcb
    [ShuntCurrentMeter.kicad_pcb]
2023-11-10 multi cell meter schema + pcb
    [MultiCellVoltMeter.kicad_pcb, MultiCellVoltMeter.kicad_sch]
2023-11-10 Create initial files for ADC unit test
2023-11-10 Added ADC tests
2023-11-10 Fix test_adc - find_median:Fail
    [ADC_test.c]
2023-11-13 added adc library
2023-11-13 updated main for new adc related functions
2023-11-13 fixed led indicator
2023-11-13 better testing data for temperature
2023-11-13 fixed current and temperature convertion bugs
2023-11-13 updated current routine
2023-11-14 enable HSI for ADC
2023-11-15 refactored adc for better testing
2023-11-15 Added Print Output
2023-11-15 fixed dependency according to new libadc
    [test_adc.c]
2023-11-15 TDD, libmosfet failed test, Not Implemented.
    [test_mosfet_control.c]
2023-11-15 added MAPPING documentation
    [MAPPING.xlsx]
2023-11-15 Add new MUX Board & Datasheet
    [Mux.kicad_pcb, Mux.kicad_sch]
2023-11-15 added battery control routine
2023-11-15 added more prototypes
2023-11-15 added temperature test
2023-11-16 temperature check ready
2023-11-16 TDD, should failed current test.
2023-11-16 added current_check()
2023-11-16 added current discharge test
2023-11-21 Add Mux board v2.1
    [Mux.kicad_pcb, Mux.kicad_sch]
2023-11-21 Battery Manger ready
2023-11-21 test battery manager ready
2023-11-21 changed truth table
    [MosfetPowerControl.kicad_sch]
2023-11-21 replaced battery control with battery_manager
    [main.c]
2023-11-21 modified discharging current test
2023-11-23 - Data for lm35 now is collected using A1 and A2 instead of using mux - Cleaned code (removed unused variables, old comments) - Added support for A2 input - Fixed a bug in find_median() (out of bound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
    [main.c]
2023-11-24 temp sensor using dedicated adc pins now
2023-11-24 DATA AND PIN MAPPING UPDATE
    [MAPPING.xlsx]
2023-11-24 updated test_adc for new decoupled adc functions
2023-11-24 fixed charging and discharging
    [test_mosfet_control.c]
2023-11-24 new temperature routine logic
2023-11-24 Fixed A2 pin input Fixed USART output for Mux Added decimal point for temperature measurement Removed useless Temp calculations from mux USART output Limited channels to 4
    [main.c]
2023-11-28 new temperature_check logic
2023-11-28 adc settings
2023-11-28 Enabled PA1 PA4 for Temp Sensor inputs
2023-11-28 modified temperature check
2023-12-01 Added Mosfet control logic Added battery states
